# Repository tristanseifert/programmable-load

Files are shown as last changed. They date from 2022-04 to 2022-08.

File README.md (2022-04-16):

# Programmable Load
A DC programmable load with lots of fun and exciting features, featuring firmware that doesn't suck.

Additional documentation [is available here.](https://wiki.trist.network/books/programmable-load) You can also read about some of the progress on my blog, [starting here.](https://blraaz.me/hardware/2022/04/13/programmable-load-intro.html)

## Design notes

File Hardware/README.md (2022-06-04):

Here is where the hardware part of the project lives. This consists of a few different boards:

- analog: A 300W load board, based around up to four individual channels, each with their own MOSFET and current sense resistor. Each channel may be individually controlled, and its current individually sensed via a 24-bit ADC. Both the ADC and current drive DAC are connected via a high-speed SPI bus. The board also features a precision 2.5V voltage reference shared by all analog components, as well as a programmable clock generator for the ADC sampling clock.
- controller: Main board, in charge of communicating with external devices (via USB or Ethernet,) driving the user interface, and running the actual control loop for whatever algorithm is desired. It also contains the analog circuitry for sensing input voltage from one of several sources.
- driver: Old I2C-based analog load board. No longer supported, should be removed soon.
- front: Front panel board; features some indicator lights, buttons, and breakout for the display. Mounted vertically to front panel of the system.
- front-bonus-display: An additional secondary (optional) character display, adjacent to the input jacks. It's used to display some information about the current set point, drawn current/voltage, and so forth in addition to the main display.
- rear: Various connectors exposed on the rear of the device, such as USB and Ethernet. It also has a pulse shaper for the external trigger. It's mounted parallel to the rear panel of the system.

All of these boards connect to the controller in some way, shape or form. Each board in turn has an EEPROM, which identifies its type, and provides a unique serial number. This is used by the software to figure out what's connected, and what features to offer.

## Front Panels
The `panels` directory contains front and rear panels, designed with [Front Panel Designer](https://www.frontpanelexpress.com/front-panel-designer) and to be manufactured by Front Panel Express. These panels are meant to replace the existing bare aluminum panels that come standard with a [Hammond 1598JBK](https://www.hammfg.com/part/1598JBK) enclosure, for which the boards are designed.

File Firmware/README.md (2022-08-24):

# Programmable Load Firmware
This directory contains the real-time firmware for the programmable load, to be built using the llvm (version 13) `arm-none-unknown-eabi` toolchain. It runs on the M4 core of the [STM32MP151 SoC](https://www.st.com/en/microcontrollers-microprocessors/stm32mp151.html) the programmable load is built around, running its own RTOS. It communicates with the host software (there, its counterpart is `loadd`) for remote control using the OpenAMP framework's rpmsg facilities.

Notable features include:
- Based around FreeRTOS
- Versatile set of control modes
- Clean, easily hackable code

## Building
To get started with the code, ensure you have a CMake toolchain file for your ARM toolchain. Inside a build directory (in this case, `build`) issue the following commands:

```
mkdir build
cmake -G Ninja -B build -DCMAKE_TOOLCHAIN_FILE=path/to/toolchain.cmake -DCMAKE_BUILD_TYPE=RelWithDebInfo
cmake --build build
```

## Hardware Support
Currently, only the rev 3 programmable load controller board is supported, though adding support for later reivsions is simple: this firmware has a very limited set of peripherals under its purview.

### Analog Board Support
Various types of analog boards can be supported, connected via the dedicated SPI + I²C busses. Boards are identified by means of an AT24CS32-style EEPROM on the I²C bus, which is then used to instantiate the appropriate driver in the firmware. This EEPROM also provides the board's unique serial number, as well as some additional manufacturing information, and any auxiliary board-specific data the driver needs to store (such as calibration or limits) and access at runtime.

Supported analog boards (and their drivers) are:

** None yet! Check back later :) **

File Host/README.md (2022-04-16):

# Programmable Load Host Tools
This directory contains a variety of tools that run on a computer connected to the load via USB or Ethernet.

## libload
This library implements USB communication with the load. Internally, it's a thin wrapper around libusb that provides a nicer C++ interface to the device.

When/if the load is updated to support TCP/IP communication, this library will be updated to handle that as well.

## loadutil
A command line utility, which embeds libload, used to communicate with the programmable load. This allows basic tasks like retrieving device information, controlling the device, and accessing some additional internal functions.

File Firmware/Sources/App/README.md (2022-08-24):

# Application Tasks
In this directory you'll find the application specific tasks:

- Control: Interfaces to the physical load driver hardware, collects sensor measurements and updates drive DACs.
- Rpmsg: Processes messages received from remote endpoint; handle periodic data/measurement updates

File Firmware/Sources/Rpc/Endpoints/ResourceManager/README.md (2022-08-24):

# Resource Manager RPC
This provides a driver for the remoteproc resource manager (`rproc_srm_*` kernel modules in the [ST Linux fork](https://github.com/STMicroelectronics/linux/tree/v5.15-stm32mp/drivers/remoteproc)) RPC interface. It's used to inform the Linux side of required clock and voltage regulator resources, as well as deal with peripheral assignments/reservations.

## License
Some of this code is based on ST's [STM32CubeMP1 res_mgr.c](https://github.com/STMicroelectronics/STM32CubeMP1/tree/8206e534360c77f22f616243c3ccf9311af83f33/Utilities/ResourcesManager) code, licensed under the BSD 3-clause license:

> Redistribution and use in source and binary forms, with or without modification, are permitted provided that the following conditions are met:
>
> 1. Redistributions of source code must retain the above copyright notice, this list of conditions and the following disclaimer.
> 2. Redistributions in binary form must reproduce the above copyright notice, this list of conditions and the following disclaimer in the documentation and/or other materials provided with the distribution.
> 3. Neither the name of STMicroelectronics nor the names of its contributors may be used to endorse or promote products derived from this software without specific prior written permission.
>
> THIS SOFTWARE IS PROVIDED BY THE COPYRIGHT HOLDERS AND CONTRIBUTORS "AS IS" AND ANY EXPRESS OR IMPLIED WARRANTIES, INCLUDING, BUT NOT LIMITED TO, THE IMPLIED WARRANTIES OF MERCHANTABILITY AND FITNESS FOR A PARTICULAR PURPOSE ARE DISCLAIMED. IN NO EVENT SHALL THE COPYRIGHT HOLDER OR CONTRIBUTORS BE LIABLE FOR ANY DIRECT, INDIRECT, INCIDENTAL, SPECIAL, EXEMPLARY, OR CONSEQUENTIAL DAMAGES (INCLUDING, BUT NOT LIMITED TO, PROCUREMENT OF SUBSTITUTE GOODS OR SERVICES; LOSS OF USE, DATA, OR PROFITS; OR BUSINESS INTERRUPTION) HOWEVER CAUSED AND ON ANY THEORY OF LIABILITY, WHETHER IN CONTRACT, STRICT LIABILITY, OR TORT (INCLUDING NEGLIGENCE OR OTHERWISE) ARISING IN ANY WAY OUT OF THE USE OF THIS SOFTWARE, EVEN IF ADVISED OF THE POSSIBILITY OF SUCH DAMAGE.

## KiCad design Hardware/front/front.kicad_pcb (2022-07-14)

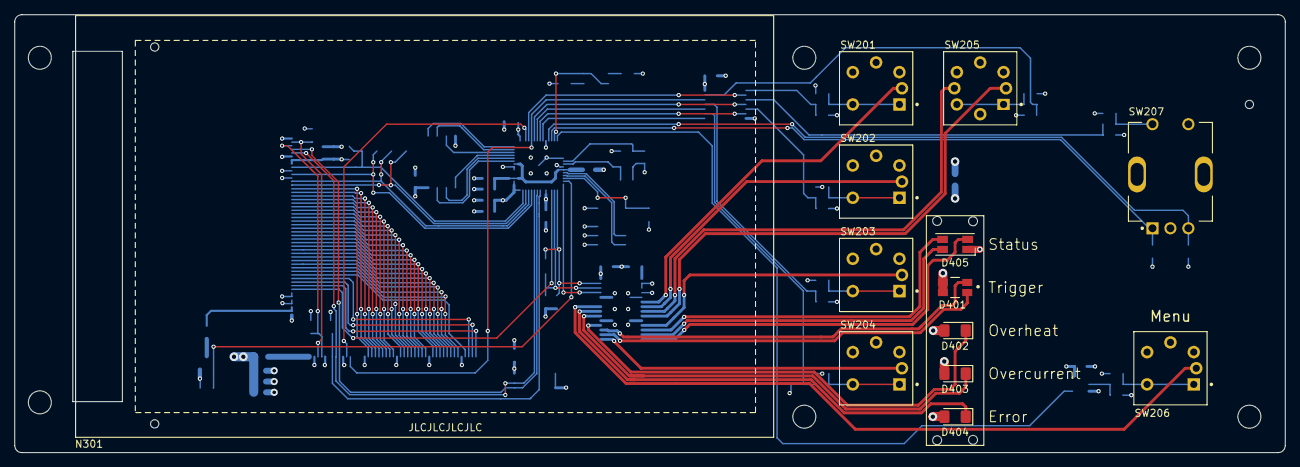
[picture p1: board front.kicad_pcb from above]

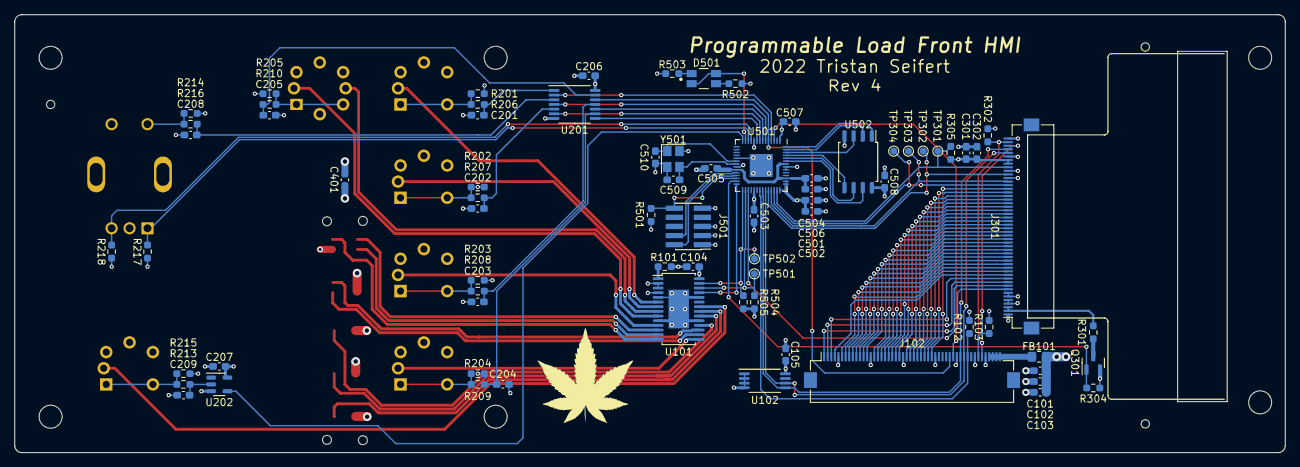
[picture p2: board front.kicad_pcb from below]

Board: 4 copper layers, 177.0 x 61.0 mm, 96 parts (74 on the bottom side), 102 nets.

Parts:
C101, C104, C105, C206, C207, C302, C501, C503, C504, C505, C507, C508: 100nF; C_0603_1608Metric_Pad1.08x0.95mm_HandSolder
C102, C103: 22µF; C_0603_1608Metric_Pad1.08x0.95mm_HandSolder
C201, C202, C203, C204, C205, C208, C209, C301, C401, C502, C506: 4.7µF; C_0603_1608Metric_Pad1.08x0.95mm_HandSolder
C509, C510: 18pF; C_0603_1608Metric_Pad1.08x0.95mm_HandSolder
D401, D501: LED_Dual_AAKK; LED-3227
D402, D403: Yellow; LED_1206_3216Metric_Pad1.42x1.75mm_HandSolder
D404: Red; LED_1206_3216Metric_Pad1.42x1.75mm_HandSolder
D405: LED_RGBA; LED_RGB_1210
FB101: FerriteBead_Small; R_0805_2012Metric_Pad1.20x1.40mm_HandSolder
H101, H102, H103, H104, H105, H106: MountingHole; MountingHole_3.2mm_M3
H107, H108, H109: MountingHole; JLCPCB-SmdAssembly-ToolingHole
J102, J301: Conn_02x25_Counter_Clockwise; Hirose_FH12-50S-0.5SH_1x50-1MP_P0.50mm_Horizontal
J501: Conn_ARM_JTAG_SWD_10; PinHeader_2x05_P1.27mm_Vertical_SMD
N301: ER-TFT040-1
Q301: AO3400A; SOT-23
R101: 2k; R_0603_1608Metric_Pad0.98x0.95mm_HandSolder
R102, R103, R201, R202, R203, R204, R205, R214, R215, R217, R218, R302, R304, R305, R501: 10k; R_0603_1608Metric_Pad0.98x0.95mm_HandSolder
R206, R207, R208, R209, R210, R213, R216, R502, R503: 1k; R_0603_1608Metric_Pad0.98x0.95mm_HandSolder
R301: 2R2; R_0603_1608Metric_Pad0.98x0.95mm_HandSolder
R504, R505: 2k2; R_0603_1608Metric_Pad0.98x0.95mm_HandSolder
SW201, SW202, SW203, SW204: B3W-9002-Y1C; Omron-B3W-90XX-X1X
SW205: B3W-9000-RHG2C; Omron-B3W-90XX-X2X
SW206: B3W-9002-G1G; Omron-B3W-90XX-X1X
SW207: TT EN11; TT_Electronics-EN11-HSM1AF15-0
TP301: /SPI_CS; TestPoint_Pad_D1.0mm
TP302: SPI_SCK; TestPoint_Pad_D1.0mm
TP303: SPI_MOSI; TestPoint_Pad_D1.0mm
TP304: SPI_MISO; TestPoint_Pad_D1.0mm
TP501: I²C_SCL; TestPoint_Pad_D1.0mm
TP502: I²C_SDA; TestPoint_Pad_D1.0mm
U101: PCA9955B; HTSSOP-28-1EP_4.4x9.7mm_P0.65mm_EP2.85x5.4mm
U102: AT24CS32-XHM; TSSOP-8_4.4x3mm_P0.65mm
U201: 74LV14; TSSOP-14_4.4x5mm_P0.65mm
U202: 74LVC1G14GV; SOT-23-5
U501: RP2040; QFN-56-1EP_7x7mm_P0.4mm_EP3.2x3.2mm
U502: W25Q128JVS; SOIC-8_5.23x5.23mm_P1.27mm
Y501: 12MHz; Crystal_SMD_3225-4Pin_3.2x2.5mm

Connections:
+1V1: C504.1, C505.1, C506.1, U501.23 (DVDD), U501.45 (VREG_VOUT), U501.50 (DVDD)
+3V3: C101.1, C102.1, C103.1, C104.1, C105.1, C206.1, C207.1, C301.1, C302.1, C401.1, C501.1, C502.1, C503.1, C507.1, C508.1, D401.1 (A1), D401.2 (A2), D402.2 (A), D403.2 (A), D404.2 (A), D405.1 (A), FB101.2, J301.1, J301.4, J301.5, J301.39, J301.41, J301.43, J301.44, J501.1 (VTref), R102.2, R103.2, R201.2, R202.2, R203.2, R204.2, R205.2, R214.2, R215.2, R217.1, R218.1, R302.2, R305.2, R501.2, R502.1, R504.2, R505.2, SW201.A, SW202.A, SW203.A, SW204.A, SW205.A1, SW205.A2, SW206.A, U101.4 (AD2), U101.28 (VCC), U102.8 (VCC), U201.14 (3.3V), U202.5 (VCC), U501.1 (IOVDD), U501.10 (IOVDD), U501.22 (IOVDD), U501.33 (IOVDD), U501.42 (IOVDD), U501.43 (ADC_AVDD), U501.44 (VREG_IN), U501.48 (USB_VDD), U501.49 (IOVDD), U502.8 (VCC)
/B0: J102.31, J301.36
/B1: J102.30, J301.35
/B2: J102.29, J301.34
/B3: J102.28, J301.33
/B4: J102.27, J301.32
/B5: J102.26, J301.31
/B6: J102.25, J301.30
/B7: J102.24, J301.29
/DISP_DE: J102.4, J301.12
/DISP_HSYNC: J102.2, J301.10
/DISP_PCLK: J102.3, J301.11
/DISP_PWM: Q301.1 (G), R304.1, U501.27 (GPIO16)
/DISP_SCL: R504.1, TP501.1, U101.26 (SCL), U501.30 (GPIO19)
/DISP_SDA: R505.1, TP502.1, U101.27 (SDA), U501.29 (GPIO18)
/DISP_VSYNC: J102.1, J301.9
/ENCODER_A: R217.2, SW207.A, U501.12 (GPIO9)
/ENCODER_B: R218.2, SW207.B, U501.11 (GPIO8)
/Embedded Controller/FLASH_IO0: U501.53 (QSPI_SD0), U502.5 (DI(IO0))
/Embedded Controller/FLASH_IO1: U501.55 (QSPI_SD1), U502.2 (DO(IO1))
/Embedded Controller/FLASH_IO2: U501.54 (QSPI_SD2), U502.3 (IO2)
/Embedded Controller/FLASH_IO3: U501.51 (QSPI_SD3), U502.7 (IO3)
/Embedded Controller/FLASH_SCK: U501.52 (QSPI_SCLK), U502.6 (CLK)
/Embedded Controller/STATUSLED: D501.2 (A2), D501.3 (K1), U501.13 (GPIO10)
/Embedded Controller/SWCLK: J501.4 (SWDCLK/TCK), U501.24 (SWCLK)
/Embedded Controller/SWD: J501.2 (SWDIO/TMS), U501.25 (SWD)
/Embedded Controller/XIN: C510.1, U501.20 (XIN), Y501.1
/Embedded Controller/XOUT: C509.1, U501.21 (XOUT), Y501.3
/Embedded Controller/~FLASH_CS: U501.56 (QSPI_SS), U502.1 (~CS)
/Embedded Controller/~RESET: J501.10 (~RESET), R501.1, U501.26 (RUN)
/G0: J102.22, J301.28
/G1: J102.21, J301.27
/G2: J102.20, J301.26
/G3: J102.19, J301.25
/G4: J102.18, J301.24
/G5: J102.17, J301.23
/G6: J102.16, J301.22
/G7: J102.15, J301.21
/LCD, Backlight driver/LEDK: J301.2, J301.3, R301.1
/LED_EN_G: SW205.K2 (K), U101.8 (LED2)
/LED_EN_R: SW205.K1 (K), U101.9 (LED3)
/LED_ERROR: D404.1 (K), U101.21 (LED13)
/LED_MENU: SW206.K, U101.22 (LED14)
/LED_MODE_CC: SW201.K, U101.6 (LED0)
/LED_MODE_CV: SW202.K, U101.7 (LED1)
/LED_MODE_CW: SW203.K, U101.11 (LED4)
/LED_MODE_EXT: SW204.K, U101.15 (LED8)
/LED_OVRCURR: D403.1 (K), U101.20 (LED12)
/LED_OVRHEAT: D402.1 (K), U101.18 (LED11)
/LED_STATUS_B: D405.4 (BK), U101.13 (LED6)
/LED_STATUS_G: D405.3 (GK), U101.12 (LED5)
/LED_STATUS_R: D405.2 (RK), U101.14 (LED7)
/LED_TRIGGER1: D401.3 (K1), U101.17 (LED10)
/LED_TRIGGER2: D401.4 (K2), U101.16 (LED9)
/R0: J102.13, J301.20
/R1: J102.12, J301.19
/R2: J102.11, J301.18
/R3: J102.10, J301.17
/R4: J102.9, J301.16
/R5: J102.8, J301.15
/R6: J102.7, J301.14
/R7: J102.6, J301.13
/SCL: J102.40, J301.46, U102.6 (SCL), U501.37 (GPIO25)
/SDA: J102.39, J301.47, U102.5 (SDA), U501.36 (GPIO24)
/SPI_MISO: J301.37, TP304.1, U501.40 (GPIO28_ADC2)
/SPI_MOSI: J301.38, TP303.1, U501.39 (GPIO27_ADC1)
/SPI_SCK: J301.40, TP302.1, U501.38 (GPIO26_ADC0)
/SW_ENABLE: J102.36, U201.12, U501.5 (GPIO3)
/SW_ENCODER: U201.4, U501.6 (GPIO4)
/SW_MENU: U202.4, U501.14 (GPIO11)
/SW_MODE_CC: U201.2, U501.4 (GPIO2)
/SW_MODE_CV: U201.6, U501.8 (GPIO6)
/SW_MODE_CW: U201.10, U501.7 (GPIO5)
/SW_MODE_EXT: U201.8, U501.9 (GPIO7)
/~DISP_RESET: J301.8, U501.31 (GPIO20)
/~HOST_IRQ: J102.41, R102.1, U501.35 (GPIO23)
/~LED_RESET: U101.25 (~RESET), U501.28 (GPIO17)
/~SPI_CS: J301.42, R305.1, TP301.1, U501.41 (GPIO29_ADC3)
/~SYS_RESET: J102.37, U501.3 (GPIO1)
/~TOUCH_IRQ: J102.44, J301.48, R103.1
/~TOUCH_RESET: J102.45, J301.49, R302.1
GND: C101.2, C102.2, C103.2, C104.2, C105.2, C201.2, C202.2, C203.2, C204.2, C205.2, C206.2, C207.2, C208.2, C209.2, C301.2, C302.2, C401.2, C501.2, C502.2, C503.2, C504.2, C505.2, C506.2, C507.2, C508.2, C509.2, C510.2, J102.5, J102.14, J102.23, J102.32, J102.38, J102.43, J102.46, J301.6, J301.7, J301.45, J301.50, J501.3 (GND), J501.5 (GND), J501.9 (GNDDetect), Q301.2 (S), R101.1, R304.2, R503.1, SW201.3, SW201.4, SW202.3, SW202.4, SW203.3, SW203.4, SW204.3, SW204.4, SW205.3, SW205.4, SW206.3, SW206.4, SW207.C, SW207.S2, U101.2 (AD0), U101.3 (AD1), U101.5 (~OE), U101.10 (GND), U101.19 (GND), U101.24 (GND), U101.29 (GND), U102.1 (A0), U102.2 (A1), U102.3 (A2), U102.4 (GND), U201.7 (GND), U202.3 (GND), U501.19 (TESTEN), U501.57 (GND), U502.4 (GND), Y501.2, Y501.4
unnamed: C201.1, R206.2, U201.1
unnamed: C202.1, R207.2, U201.5
unnamed: C203.1, R208.2, U201.11
unnamed: C204.1, R209.2, U201.9
unnamed: C205.1, R210.2, U201.13
unnamed: C208.1, R216.2, U201.3
unnamed: C209.1, R213.1, U202.2
unnamed: D501.1 (A1), R502.2
unnamed: D501.4 (K2), R503.2
unnamed: FB101.1, J102.47, J102.48, J102.49, J102.50
unnamed: Q301.3 (D), R301.2
unnamed: R201.1, R206.1, SW201.1, SW201.2
unnamed: R202.1, R207.1, SW202.1, SW202.2
unnamed: R203.1, R208.1, SW203.1, SW203.2
unnamed: R204.1, R209.1, SW204.1, SW204.2
unnamed: R205.1, R210.1, SW205.1, SW205.2
unnamed: R213.2, R215.1, SW206.1, SW206.2
unnamed: R214.1, R216.1, SW207.S1
unnamed: R101.2, U101.1 (REXT)

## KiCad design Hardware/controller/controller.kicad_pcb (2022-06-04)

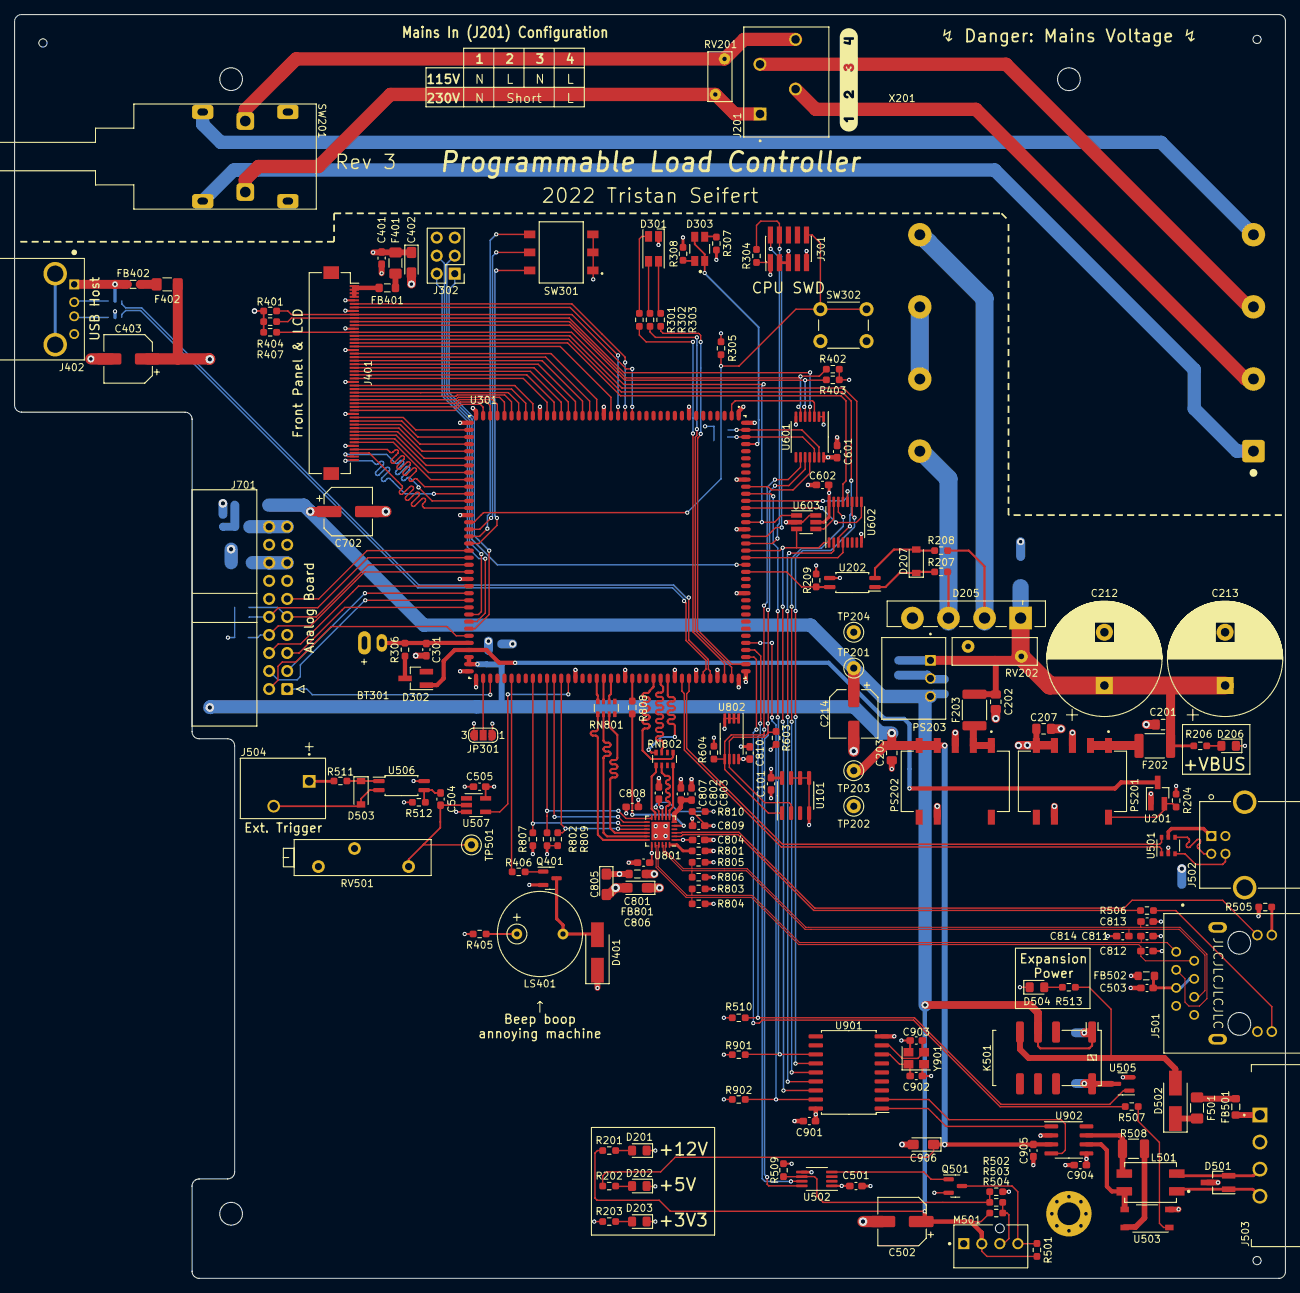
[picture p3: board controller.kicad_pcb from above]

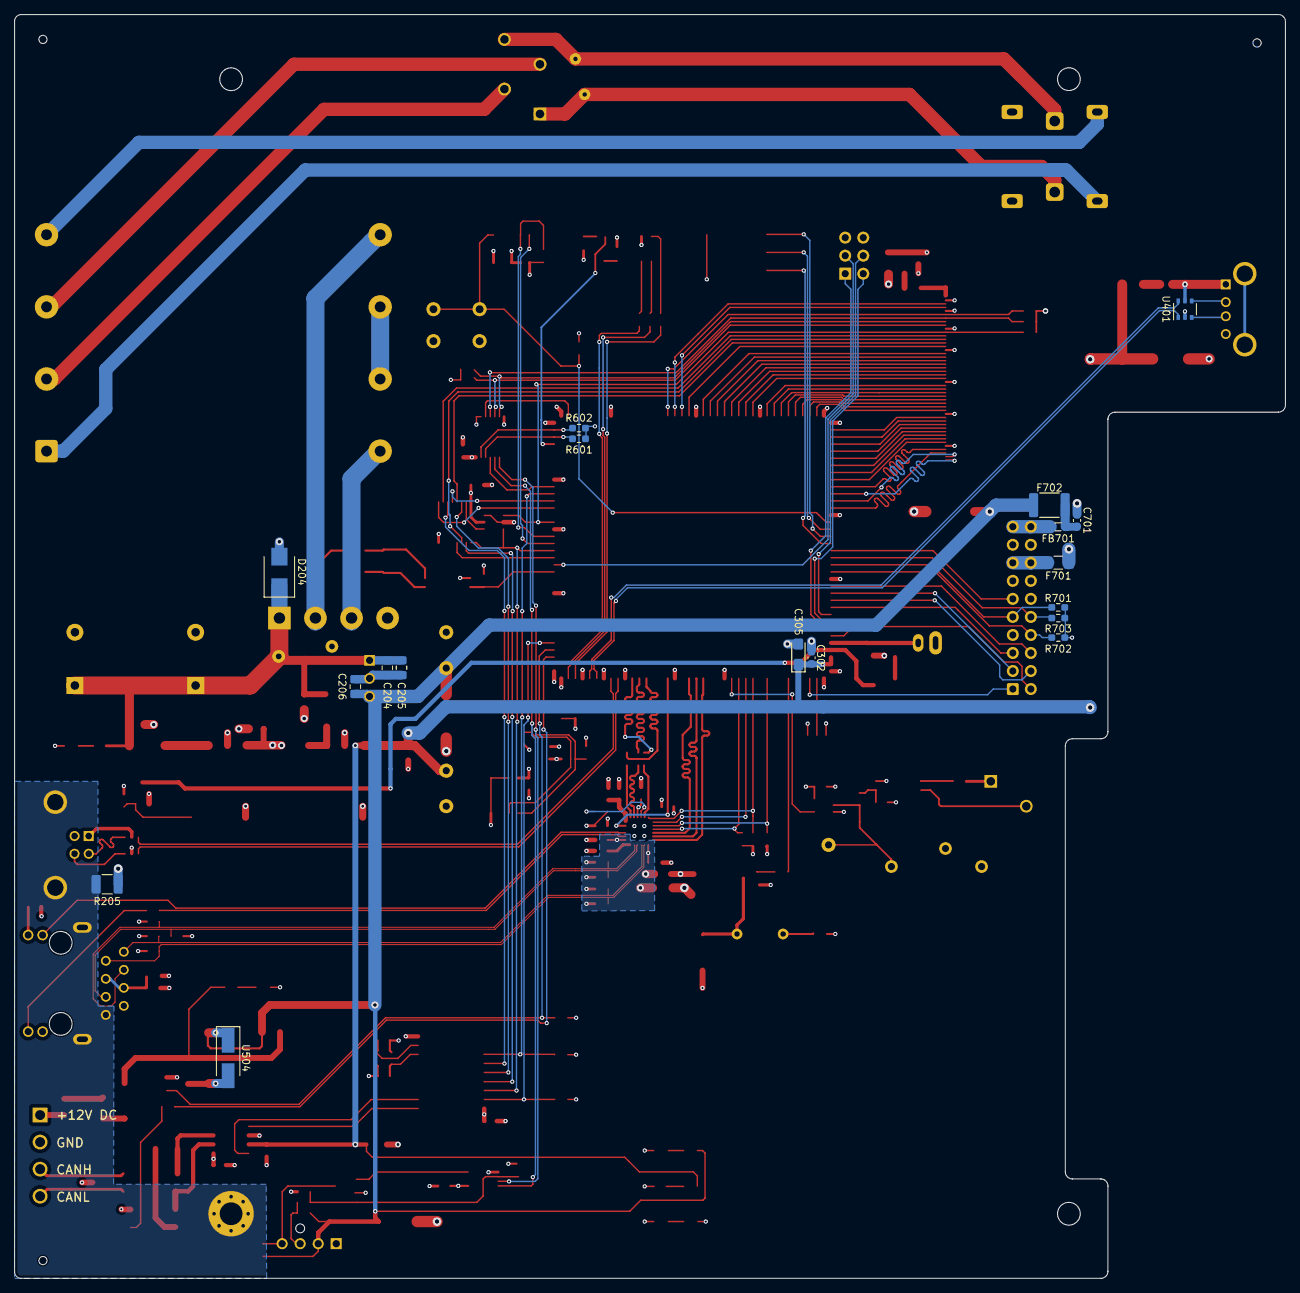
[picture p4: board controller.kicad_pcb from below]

Board: 4 copper layers, 179.0 x 178.0 mm, 193 parts (18 on the bottom side), 192 nets.

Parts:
BT301: ML-1220; Panasonic-ML-1220_V1AN-0-0
C101, C301, C302, C401, C501, C505, C601, C602, C701, C810, C901, C904, C905: 100nF; C_0603_1608Metric_Pad1.08x0.95mm_HandSolder
C201, C202, C204, C205, C206: 10µF; C_0805_2012Metric_Pad1.18x1.45mm_HandSolder
C203, C207: 22µF; C_0805_2012Metric_Pad1.18x1.45mm_HandSolder
C212, C213: 3300µF; CP_Radial_D16.0mm_P7.50mm
C214, C403, C502, C702: 33µF; CP_Elec_6.3x5.7
C305, C402, C805, C806, C906: 10µF; CP_EIA-3216-18_Kemet-A_Pad1.58x1.35mm_HandSolder
C503: 22nF; C_0603_1608Metric_Pad1.08x0.95mm_HandSolder
C504, C803: 1µF; C_0603_1608Metric_Pad1.08x0.95mm_HandSolder
C801, C804, C807, C808, C809: 10nF; C_0603_1608Metric_Pad1.08x0.95mm_HandSolder
C802: 470pF; C_0603_1608Metric_Pad1.08x0.95mm_HandSolder
C811, C812, C813, C814: 22pF; C_0603_1608Metric_Pad1.08x0.95mm_HandSolder
C902, C903: 15pF; C_0603_1608Metric_Pad1.08x0.95mm_HandSolder
D201, D202, D203, D206, D504: Green; LED_0805_2012Metric_Pad1.15x1.40mm_HandSolder
D204: 824521241; D_SMB
D205: GBU4M; Diode_Bridge_Vishay_GBU
D207, D503: 1N4148W; D_SOD-123
D301: LED_RGBA; LED_RGB_1210
D302: BAS40HE3; SOT-23_Handsoldering
D303: LED_Dual_AAKK; LED-3227
D401: SM4007; D_SMA_Handsoldering
D501: ESDONCAN1; SOT-23_Handsoldering
D502: Panjit SS14; D_SMA_Handsoldering
F202, F203: .3A; Fuse_1812_4532Metric_Pad1.30x3.40mm_HandSolder
F401, F402, F501, F701: 500mA; Fuse_1206_3216Metric_Pad1.42x1.75mm_HandSolder
F702: 1.6A; Fuse_1812_4532Metric_Pad1.30x3.40mm_HandSolder
FB401, FB402, FB501, FB502, FB701, FB801: FerriteBead_Small; L_0805_2012Metric_Pad1.05x1.20mm_HandSolder
H101, H102, H104: MountingHole; MountingHole_3.2mm_M3
H103: MountingHole; MountingHole_3.2mm_M3_Pad_Via
H105, H106, H107: MountingHole; JLCPCB-SmdAssembly-ToolingHole
J201: Conn_01x04; CUI_TBL002A-350-04GR-2OR
J301: Conn_ARM_JTAG_SWD_10; PinHeader_2x05_P1.27mm_Vertical_SMD
J302: Conn_02x03_Odd_Even; PinHeader_2x03_P2.54mm_Vertical
J401: Conn_02x25_Counter_Clockwise; Hirose_FH12-50S-0.5SH_1x50-1MP_P0.50mm_Horizontal
J402: USB_A; CUI_UJ2-AH-4-TH
J501: ARJM11C7-009-AB; Abracon-ARJM11C7
J502: USB_B; CUI_UJ2-BH-2-TH
J503: TBP02R1W-381-04BE; CUI_TBP02R1W-381-04BE
J504: Screw_Terminal_01x02; CUI_TBL002A-350-02GR-2OR
J701: Conn_02x10_Odd_Even; IDC-Header_2x10_P2.54mm_Horizontal
JP301: SolderJumper_3_Open; SolderJumper-3_P1.3mm_Open_RoundedPad1.0x1.5mm_NumberLabels
K501: EE2-12NU; Relay_DPDT_Kemet_EE2_NU
L501: DR331-513BE; Bourns-DR331-0-0-MFG
LS401: Speaker; PUI-AT-1224-TWT
M501: Fan_4pin; Molex-47053-1000-MFG
PS201: V78E03-1000-SMT-TR; CONV_V78E03-1000-SMT-TR
PS202: V78E05-1000-SMT-TR; CONV_V78E03-1000-SMT-TR
PS203: P7812-2000-S; CONV_P7812-2000-S
Q401, Q501: MMBT3904; SOT-23
R201, R209, R501, R504, R510, R513: 4k7; R_0603_1608Metric_Pad0.98x0.95mm_HandSolder
R202, R402, R403, R601, R602, R603, R604, R701, R702, R802, R807: 2k2; R_0603_1608Metric_Pad0.98x0.95mm_HandSolder
R203, R301, R302, R303, R304, R307, R308, R507: 1k; R_0603_1608Metric_Pad0.98x0.95mm_HandSolder
R204, R305, R401, R404, R407, R502, R509, R703, R809, R810, R901, R902: 10k; R_0603_1608Metric_Pad0.98x0.95mm_HandSolder
R205: 0R; R_1210_3225Metric_Pad1.30x2.65mm_HandSolder
R206, R207, R208: 7k5; R_0603_1608Metric_Pad0.98x0.95mm_HandSolder
R306: 100R; R_0603_1608Metric_Pad0.98x0.95mm_HandSolder
R405, R406, R505, R506: 330R; R_0603_1608Metric_Pad0.98x0.95mm_HandSolder
R503: 27k4; R_0603_1608Metric_Pad0.98x0.95mm_HandSolder
R508: 100R; R_1210_3225Metric_Pad1.30x2.65mm_HandSolder
R511: 200R; R_0603_1608Metric_Pad0.98x0.95mm_HandSolder
R512: 47k; R_0603_1608Metric_Pad0.98x0.95mm_HandSolder
R801: 12k1 1%; R_0603_1608Metric_Pad0.98x0.95mm_HandSolder
R803, R804, R805, R806: 49R9; R_0603_1608Metric_Pad0.98x0.95mm_HandSolder
R808: 33R; R_0603_1608Metric_Pad0.98x0.95mm_HandSolder
RN801, RN802: 33R; R_Array_Convex_4x0603
RV201: Varistor; RV_Disc_D7mm_W3.4mm_P5mm
RV202: 470KD10; RV_Disc_D12mm_W3.9mm_P7.5mm
RV501: 500k; Potentiometer_Bourns_3006P_Horizontal
SW201: NE1838EE
SW301: SW_DIP_x03; CUI-DS04-254-2-03BK-SMT
SW302: SW_MEC_5E; SW_PUSH_6mm
TP201: +12V; TestPoint_Keystone_5000-5004_Miniature
TP202: +3V3; TestPoint_Keystone_5000-5004_Miniature
TP203: +5V; TestPoint_Keystone_5000-5004_Miniature
TP204: GND; TestPoint_Keystone_5000-5004_Miniature
TP501: Trigger; TestPoint_Keystone_5000-5004_Miniature
U101: LM75B; SOIC-8_3.9x4.9mm_P1.27mm
U201: TCM809TVNB713; SOT-23_Handsoldering
U202, U506: FODM217B; SOP-4_4.4x2.6mm_P1.27mm
U301: MYC-YA151C-4E512D-65-C-T; MYCYA151C4E512D65CT
U401, U501: IP4234CZ6-ALT; TSOP-6_1.65x3.05mm_P0.95mm
U502: EMC2101-R; MSOP-8_3x3mm_P0.65mm
U503: TLP170A; MFSOP6-4_4.4x3.6mm_P1.27mm
U504: SM4007; D_SMA_Handsoldering
U505: MMBT3904; SOT-23
U507: 74LVC1G17; SOT-23-5_HandSoldering
U601: PCA9543A; TSSOP-14_4.4x5mm_P0.65mm
U602: SN74CBTLV3257; TSSOP-16_4.4x5mm_P0.65mm
U603: 74LVC1G0832; SOT-23-6_Handsoldering
U801: LAN8720A; QFN-24-1EP_4x4mm_P0.5mm_EP2.6x2.6mm
U802: AT24MAC402; TSSOP-8_4.4x3mm_P0.65mm
U901: MCP2515-xSO; SOIC-18W_7.5x11.6mm_P1.27mm
U902: MCP2542WFD; SOIC-8_3.9x4.9mm_P1.27mm
X201: FS20-1800-C2; Triad-FS16-2250-C2
Y901: 16MHz; Crystal_SMD_3225-4Pin_3.2x2.5mm
kibuzzard-62915F53: G***; kibuzzard-62915F53

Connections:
+3V3: C101.2, C207.1, C401.2, C402.1, C501.2, C505.2, C601.1, C602.1, C805.1, C807.1, C808.1, C809.1, C810.2, C901.1, C904.1, D301.1 (A), D401.1 (K), F401.1, F701.1, FB502.1, FB801.1, J301.1 (VTref), J302.6, J501.9 (RLED+), JP301.3 (B), PS201.4 (+VOUT), PS201.5 (+VOUT), R203.1, R209.1, R304.2, R305.2, R307.1, R401.2, R402.2, R403.2, R404.2, R405.2, R407.2, R509.1, R601.2, R602.2, R603.2, R604.2, R701.2, R702.2, R703.2, R802.1, R807.1, R809.2, R810.1, R901.2, R902.2, SW301.1, SW301.2, SW301.3, TP202.1, U101.8 (+Vs), U502.1 (VCC), U506.4, U507.5 (VCC), U601.14 (VCC), U602.16 (VCC), U603.5 (VCC), U801.9 (VDDIO), U802.8 (VCC), U901.18 (VDD), U902.5 (VIO)
+3V3A: C801.1, C804.1, C806.1, FB801.2, R803.1, R804.1, R805.1, R806.1, U801.1 (VDD2A), U801.19 (VDD1A)
+5V: C203.1, C302.1, C305.1, C403.1, C905.1, C906.1, F402.2, PS202.4 (+VOUT), PS202.5 (+VOUT), R202.1, TP203.1, U301.72 (VDD_{5V}), U301.73 (VDD_{5V}), U902.3 (VCC)
+12V: C206.2, C214.1, C502.1, C702.1, F702.2, K501.1, K501.4, M501.2 (+), PS203.3 (+VO), R201.1, R501.2, R504.2, TP201.1, U504.1 (K)
+BATT: BT301.1 (+), C301.1, R306.2, U301.70 (V_{BAT})
/ANA_MISO: J701.3, U301.63 (PH7)
/ANA_MOSI: J701.6, U301.62 (PF11)
/ANA_SCK: J701.5, U301.65 (PH6)
/ANA_SCL: J701.9, R701.1, U301.59 (PF14)
/ANA_SDA: J701.8, R702.1, U301.60 (PF15)
/ANA_SEL0: J701.4, U301.64 (PH5)
/ANA_SEL1: J701.2, U301.69 (PA12)
/ANA_SEL2: J701.1, U301.77 (PE11)
/BEEPER: R406.1, U301.80 (PA3)
/CANH: L501.3, R508.2, U902.7 (CANH)
/CANL: L501.4, U503.4, U902.6 (CANL)
/CAN_TERM_EN: R507.2, U301.115 (PF7)
/CPU/BOOT0: SW301.4, U301.55 (BOOT0)
/CPU/BOOT1: SW301.5, U301.54 (BOOT1)
/CPU/BOOT2: SW301.6, U301.56 (BOOT2)
/CPU/Bus Multiplexers/~SPI_MUX_OE: U602.15 (~OE), U603.4
/CPU/CAN_SPI_MISO: U602.14 (4B1), U901.14 (SI)
/CPU/CAN_SPI_MOSI: U602.2 (1B1), U901.15 (SO)
/CPU/CAN_SPI_SCK: U602.11 (3B1), U901.13 (SCK)
/CPU/ETH_CLK: R808.1, U301.97 (PA1/ETH_RCLK)
/CPU/ETH_CRS_DV: RN802.8 (R1.2), U301.102 (PA7/ETH_RCTL)
/CPU/ETH_MDC: U301.86 (PC1/ETH_MDC), U801.13 (MDC)
/CPU/ETH_MDIO: R802.2, U301.85 (PA2/ETH_MDIO), U801.12 (MDIO)
/CPU/ETH_RXD0: RN802.7 (R2.2), U301.101 (PC4/ETH_RD0)
/CPU/ETH_RXD1: RN802.5 (R4.2), U301.100 (PC5/ETH_RD1)
/CPU/ETH_TXD0: RN801.7 (R2.2), U301.93 (PG13/ETH_TD0)
/CPU/ETH_TXD1: RN801.8 (R1.2), U301.92 (PG14/ETH_TD1)
/CPU/ETH_TX_EN: RN801.6 (R3.2), U301.94 (PB11/ETH_TCTL)
/CPU/Ethernet PHY/RXER: R810.2, U801.10 (RXER/PHYAD0)
/CPU/Expansion CAN Controller/CAN_RX: U901.2 (RXCAN), U902.4 (RXD)
/CPU/Expansion CAN Controller/CAN_TX: U901.1 (TXCAN), U902.1 (TXD)
/CPU/Expansion CAN Controller/OSC1: C903.1, U901.8 (OSC1), Y901.3
/CPU/Expansion CAN Controller/OSC2: C902.1, U901.7 (OSC2), Y901.1
/CPU/I2C2_SCL: R601.1, U301.146 (PH4), U601.12 (SCL)
/CPU/I2C2_SDA: R602.1, U301.147 (PZ7), U601.13 (SDA)
/CPU/SOM_PWRON: JP301.2 (C), U301.76 (KEY_WP)
/CPU/SPI3_MISO: U301.137 (PC11/MMC1_D3), U602.12 (4A)
/CPU/SPI3_MOSI: U301.129 (PB2), U602.4 (1A)
/CPU/SPI3_SCK: U301.136 (PC10/MMC1_D2), U602.9 (3A)
/CPU/STATUS_A7: D303.2 (A2), D303.3 (K1), U301.145 (PZ6)
/CPU/STATUS_B: R303.1, U301.114 (PF8)
/CPU/STATUS_G: R302.1, U301.111 (PD13)
/CPU/STATUS_R: R301.1, U301.110 (PG5)
/CPU/SWDCLK: J301.4 (SWDCLK/TCK), R304.1, U301.132 (SWCLK)
/CPU/SWDIO: J301.2 (SWDIO/TMS), U301.131 (SWDIO)
/CPU/TTY1_RX: J302.1, U301.68 (PA11)
/CPU/TTY1_TX: J302.3, U301.128 (PG11)
/CPU/TTY2_RX: J302.2, U301.67 (PB5)
/CPU/TTY2_TX: J302.4, U301.66 (PB13)
/CPU/~CAN_RESET: R902.1, U301.117 (PF9), U901.17 (~RESET)
/CPU/~CAN_SPI_CS: U301.130 (PA15), U602.1 (S), U603.3, U901.16 (~CS)
/CPU/~ETH_PHY_IRQ: R807.2, U301.83 (PA5), U801.14 (INT/REFCLKO)
/CPU/~ETH_PHY_RESET: R809.1, U301.87 (PC0), U801.15 (RST)
/CPU/~I2CMUX_IRQ: U301.139 (PD2/MMC1_CMD), U601.11 (~INT)
/CPU/~I2CMUX_RESET: U301.2 (PF0/MMC3_D0), U601.3 (~RESET)
/CPU/~RESET: J301.10 (~RESET), R305.1, SW302.1, U301.53 (~RESET)
/CPU/~SPI3_IRQ: R901.1, U301.138 (PC12/MMC1_CK), U901.12 (~INT)
/CPU_3V3: D302.1, U201.3 (VCC), U301.71 (3V3_{OUT})
/DISP_MISO: J401.17, U602.13 (4B2)
/DISP_MOSI: J401.16, U602.3 (1B2)
/DISP_SCK: J401.15, U602.10 (3B2)
/ETH_LED0: J501.11 (LLED+), U801.3 (LED1/REGOFF)
/ETH_RXN: C814.1, J501.6 (RD-), R806.2, U801.22 (RXN)
/ETH_RXP: C813.1, J501.3 (RD+), R805.2, U801.23 (RXP)
/ETH_TXN: C812.2, J501.2 (TD-), R804.2, U801.20 (TXN)
/ETH_TXP: C811.2, J501.1 (TD+), R803.2, U801.21 (TXP)
/EXP_PWR_EN: R510.2, U301.116 (PF6), U505.1 (B)
/FRONT_ENC_A: J401.7, U301.18 (PA6)
/FRONT_ENC_B: J401.6, U301.17 (PA4)
/FRONT_SCL: J401.11, R402.1, U601.6 (SCL0)
/FRONT_SDA: J401.12, R403.1, U601.5 (SDA0)
/IO_SCL: R603.1, U101.2 (SCL), U502.8 (SMCLK), U601.10 (SCL1), U802.6 (SCL)
/IO_SDA: R604.1, U101.1 (SDA), U502.7 (SMDATA), U601.9 (SDA1), U802.5 (SDA)
/LCD_B0: J401.20, U301.21 (PD9)
/LCD_B1: J401.21, U301.22 (PG12)
/LCD_B2: J401.22, U301.23 (PG10)
/LCD_B3: J401.23, U301.24 (PD10)
/LCD_B4: J401.24, U301.25 (PI4)
/LCD_B5: J401.25, U301.26 (PI5)
/LCD_B6: J401.26, U301.27 (PI6)
/LCD_B7: J401.27, U301.28 (PI7)
/LCD_DE: J401.47, U301.48 (PE13)
/LCD_G0: J401.29, U301.30 (PE14)
/LCD_G1: J401.30, U301.31 (PE6)
/LCD_G2: J401.31, U301.32 (PH13)
/LCD_G3: J401.32, U301.33 (PH14)
/LCD_G4: J401.33, U301.34 (PH15)
/LCD_G5: J401.34, U301.35 (PI0)
/LCD_G6: J401.35, U301.36 (PI1)
/LCD_G7: J401.36, U301.37 (PI2)
/LCD_HSYNC: J401.49, U301.50 (PI10)
/LCD_PCLK: J401.48, U301.51 (PG7)
/LCD_PWM: J401.18, U301.19 (PB7)
/LCD_R0: J401.38, U301.40 (PH2)
/LCD_R1: J401.39, U301.41 (PH3)
/LCD_R2: J401.40, U301.42 (PH8)
/LCD_R3: J401.41, U301.43 (PH9)
/LCD_R4: J401.42, U301.44 (PH10)
/LCD_R5: J401.43, U301.45 (PH11)
/LCD_R6: J401.44, U301.46 (PH12)
/LCD_R7: J401.45, U301.47 (PE15)
/LCD_VSYNC: J401.50, U301.49 (PI9)
/Power Supply/3V3_ENABLE: PS201.10 (ON/OFF), R204.2, U201.2 (~RESET)
/Power Supply/AC+: D205.3, R207.2, X201.5
/Power Supply/AC-: D205.2, R208.2, X201.8
/Power Supply/ACIN_L: J201.4, RV201.1, SW201.P_{1} (B)
/Power Supply/ACIN_N: J201.1, RV201.2, SW201.P_{2} (B)
/Rear IO Connections/FAN_PWM: Q501.1 (B), U502.4 (FAN)
/Rear IO Connections/FAN_TACH: R502.2, R503.2, R509.2, U502.6 (TACH)
/TRIGGER: U301.88 (PG8), U507.4
/USBD_DN: U301.105 (USB2N), U501.6
/USBD_DP: U301.104 (USB2P), U501.1
/USBH_DN: U301.108 (USB1N), U401.6
/USBH_DP: U301.107 (USB1P), U401.1
/ZERO_CROSS: R209.2, U202.4, U301.127 (PF10)
/~ANA_IRQ: J701.10, R703.1, U301.58 (PG3)
/~ANA_RESET: J701.11, U301.57 (PD8)
/~DISP_CS: J401.14, R407.1, U301.134 (PC8/MMC1_D0), U603.1
/~ETH_LED1: R506.1, U801.2 (LED2/nINTSEL)
/~FRONT_IRQ: J401.10, R404.1, U601.4 (~INT0)
/~FRONT_RESET: J401.9, R401.1, U301.16 (PB9)
GND: BT301.2 (-), C101.1, C201.1, C202.1, C203.2, C204.1, C205.1, C206.1, C207.2, C212.2, C213.2, C214.2, C301.2, C302.2, C305.2, C401.1, C402.2, C403.2, C501.1, C502.2, C503.1, C505.1, C601.2, C602.2, C701.1, C702.2, C801.2, C802.2, C803.2, C804.2, C805.2, C806.2, C807.2, C808.2, C809.2, C810.1, C811.1, C812.1, C813.2, C814.2, C901.2, C902.2, C903.2, C904.2, C905.2, C906.2, D201.1 (K), D202.1 (K), D203.1 (K), D204.2 (A2), D205.4 (-), D206.1 (K), D501.3 (common), D504.1 (K), J301.3 (GND), J301.5 (GND), J301.9 (GNDDetect), J302.5, J401.5, J401.8, J401.13, J401.19, J401.28, J401.37, J401.46, J402.4 (GND), J502.4 (GND), J503.2, J701.7, J701.13, J701.14, J701.17, J701.18, JP301.1 (A), M501.1 (-), PS201.3 (GND), PS201.7 (GND), PS202.3 (GND), PS202.7 (GND), PS203.2 (GND), Q401.2 (E), Q501.2 (E), R204.1, R205.2, R308.1, R502.1, R505.1, R510.1, R512.1, R801.2, RV202.1, RV501.2, RV501.3, SW302.2, TP204.1, U101.4 (GND), U101.5 (A2), U101.6 (A1), U101.7 (A0), U201.1 (GND), U202.3, U301.1 (GND), U301.8 (GND), U301.20 (GND), U301.29 (GND), U301.38 (GND), U301.39 (GND), U301.52 (GND), U301.61 (GND), U301.74 (GND), U301.75 (GND), U301.89 (GND), U301.96 (GND), U301.103 (GND), U301.106 (GND), U301.109 (GND), U301.112 (GND), U301.113 (GND), U301.124 (GND), U301.133 (GND), U301.140 (GND), U301.148 (GND), U401.2 (GND), U501.2 (GND), U502.5 (GND), U503.3, U505.2 (E), U507.3 (GND), U601.1 (A0), U601.2 (A1), U601.7 (GND), U602.8 (GND), U603.2 (GND), U603.6, U801.25 (VSS), U802.1 (A_{0}), U802.2 (A_{1}), U802.3 (A_{2}), U802.4 (GND), U901.9 (VSS), U902.2 (GND), Y901.2, Y901.4
GND2: H103.1, J501.8, J501.S1 (SHIELD), J501.S2 (SHIELD), J502.5 (Shield), R205.1
LINE: SW201.R_{1} (C), X201.4
NEUT: SW201.R_{2} (C), X201.1
unnamed: C504.1, RV501.1, TP501.1, U507.2
unnamed: C504.2, R512.2, U506.3
unnamed: C701.2, F702.1, FB701.2
unnamed: D201.2 (A), R201.2
unnamed: D202.2 (A), R202.2
unnamed: D203.2 (A), R203.2
unnamed: D206.2 (A), R206.2
unnamed: D207.2 (A), R208.1, U202.2
unnamed: D207.1 (K), R207.1, U202.1
unnamed: D301.4 (BK), R303.2
unnamed: D301.3 (GK), R302.2
unnamed: D301.2 (RK), R301.2
unnamed: D302.3, R306.1
unnamed: D303.1 (A1), R307.2
unnamed: D303.4 (K2), R308.2
unnamed: D401.2 (A), LS401.2, Q401.3 (C)
unnamed: D501.1 (A1), J503.4, L501.1
unnamed: D501.2 (A2), J503.3, L501.2
unnamed: D502.2 (A), K501.5, R513.2
unnamed: D502.1 (K), F501.2
unnamed: D503.2 (A), J504.2, U506.2
unnamed: D503.1 (K), R511.1, U506.1
unnamed: F401.2, FB401.1
unnamed: F402.1, FB402.2
unnamed: F501.1, FB501.2
unnamed: J201.2, X201.2
unnamed: J201.3, X201.3
unnamed: FB401.2, J401.1, J401.2, J401.3, J401.4
unnamed: J402.3 (D+), U401.3
unnamed: J402.2 (D-), U401.4
unnamed: FB402.1, J402.1 (VBUS), U401.5 (VBUS)
unnamed: C503.2, FB502.2, J501.4 (CT), J501.5 (CT)
unnamed: J501.12 (LLED-), R505.2
unnamed: J501.10 (RLED-), R506.2
unnamed: J502.3 (D+), U501.3
unnamed: J502.2 (D-), U501.4
unnamed: J502.1 (VBUS), U501.5 (VBUS)
unnamed: FB501.1, J503.1
unnamed: J504.1, R511.2
unnamed: F701.2, J701.15, J701.16
unnamed: FB701.1, J701.19, J701.20
unnamed: LS401.1, R405.1
unnamed: M501.4 (PWM), Q501.3 (C), R501.1
unnamed: M501.3 (Tacho), R503.1, R504.1
unnamed: F202.2, PS201.1 (+VIN), PS201.2 (+VIN)
unnamed: F203.2, PS202.1 (+VIN), PS202.2 (+VIN)
unnamed: Q401.1 (B), R406.2
unnamed: R507.1, U503.1
unnamed: R508.1, U503.6
unnamed: D504.2 (A), R513.1
unnamed: RN802.1 (R1.1), U801.11 (CRS_DV/MODE2)
unnamed: RN802.2 (R2.1), U801.8 (RXD0/MODE0)
unnamed: RN802.4 (R4.1), U801.7 (RXD1/MODE1)
unnamed: K501.12, U504.2 (A), U505.3 (C)
unnamed: R801.1, U801.24 (RBIAS)
unnamed: RN801.2 (R2.1), U801.17 (TXD0)
unnamed: RN801.1 (R1.1), U801.18 (TXD1)
unnamed: RN801.3 (R3.1), U801.16 (TXEN)
unnamed: C802.1, C803.1, U801.6 (VDDCR)
unnamed: R808.2, U801.5 (XTAL1/CLKIN)
unnamed: X201.6, X201.7
VBUS: C201.2, C202.2, C204.2, C205.2, C212.1, C213.1, D204.1 (A1), D205.1 (+), F202.1, F203.1, PS203.1 (+VIN), R206.1, RV202.2

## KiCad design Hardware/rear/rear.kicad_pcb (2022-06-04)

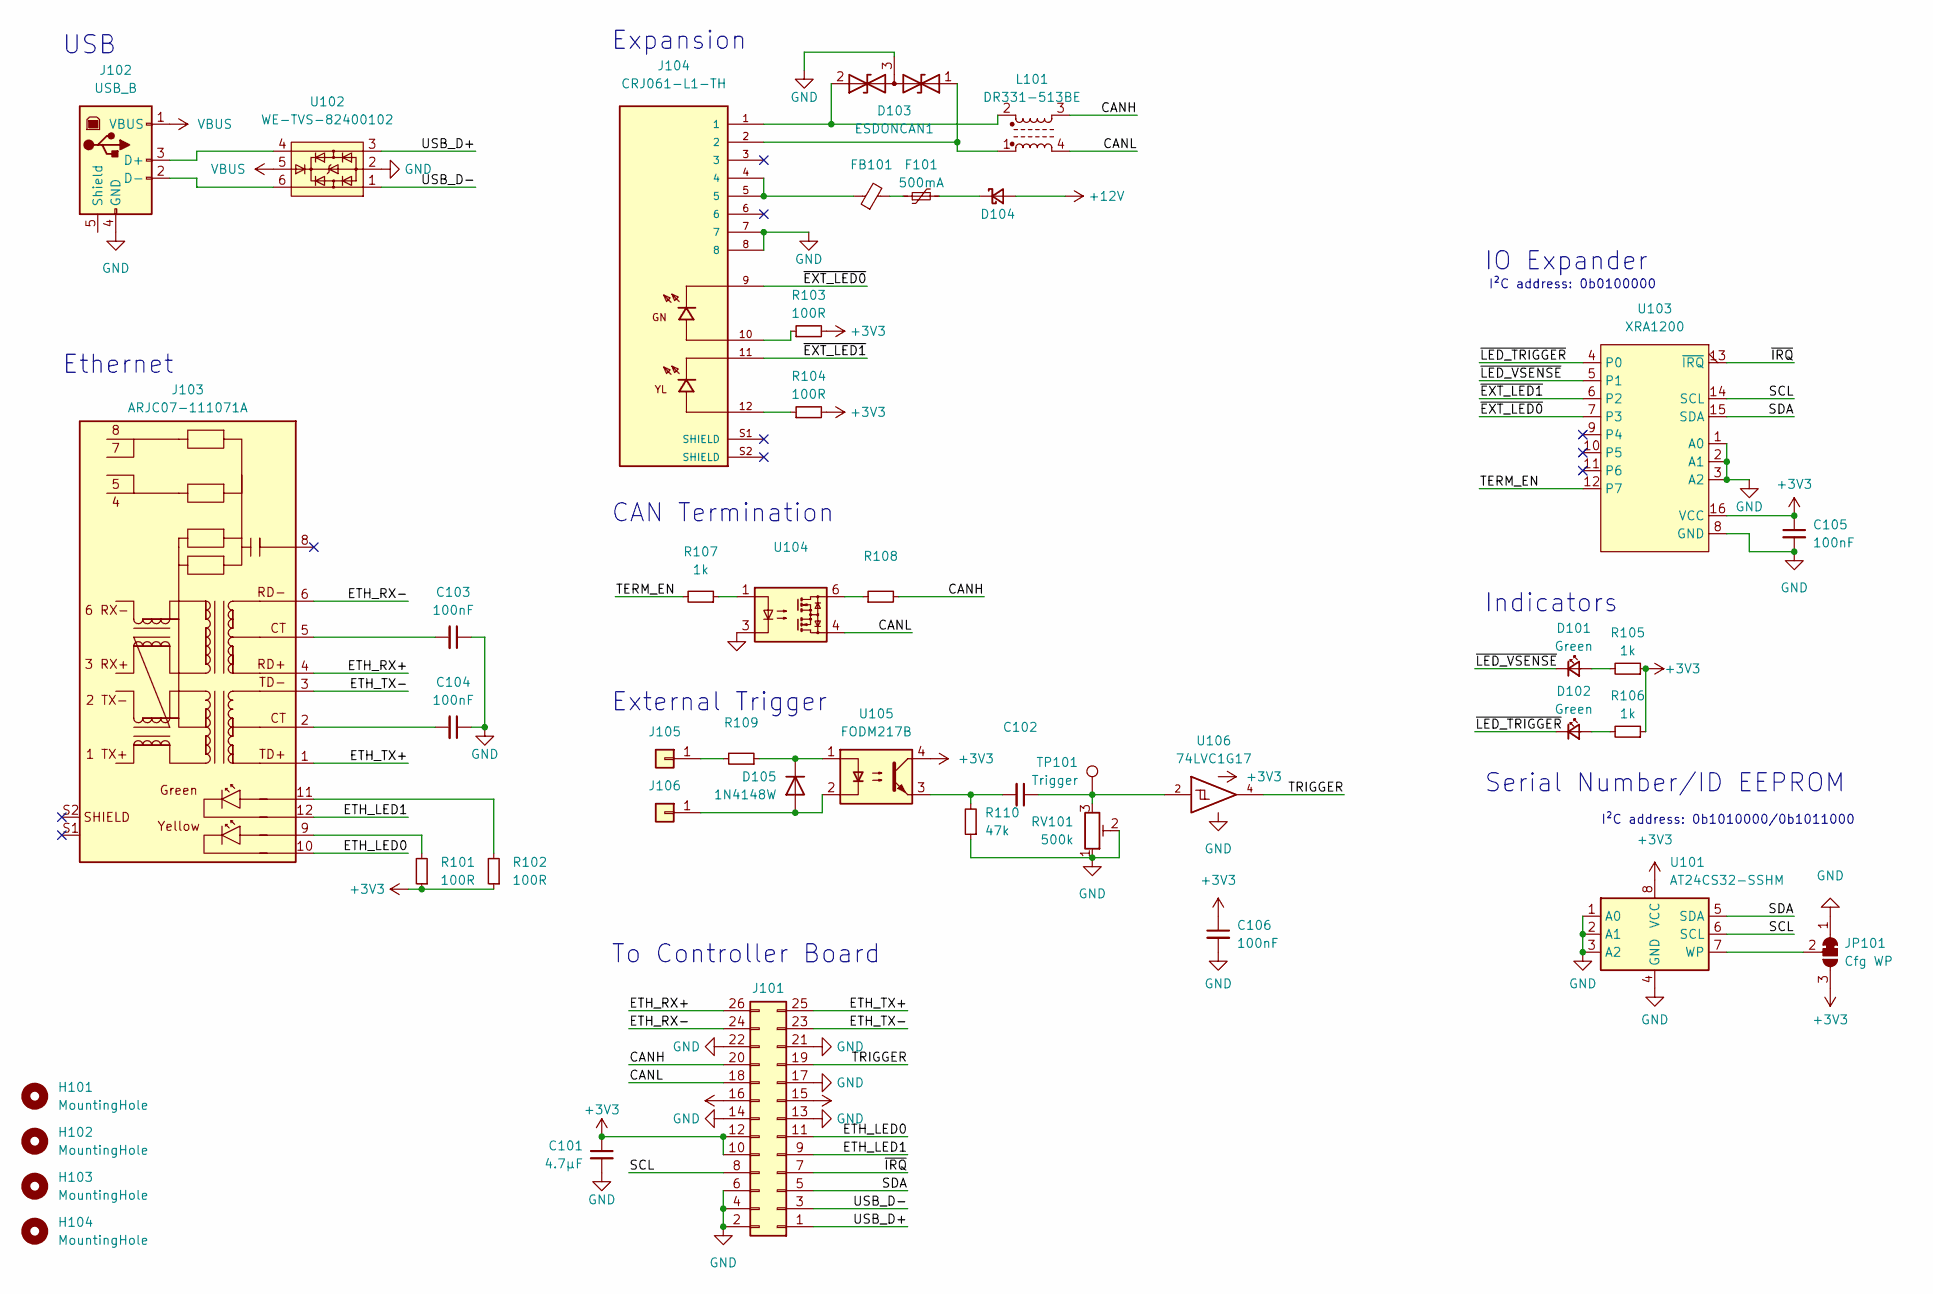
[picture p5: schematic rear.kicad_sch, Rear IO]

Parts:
C101: 4.7µF; C_0805_2012Metric_Pad1.18x1.45mm_HandSolder; MPN CL21A475KAQNNNF
C102: MPN CL21B105KBFNNNG
C103, C104, C105: 100nF; C_0805_2012Metric_Pad1.18x1.45mm_HandSolder; MPN CL21B104KACNFNC
C106: 100nF; C_0805_2012Metric_Pad1.18x1.45mm_HandSolder
D101, D102: Green; LED_0805_2012Metric_Pad1.15x1.40mm_HandSolder
D103: ESDONCAN1; SOT-23_Handsoldering; MPN ESDONCAN1LT1G
D104: Panjit SS14; D_SMA_Handsoldering; MPN SS14_R1_00001
D105: 1N4148W; D_SOD-123; MPN 1N4148W-AU_R1_000A1
F101: 500mA; Fuse_1206_3216Metric_Pad1.42x1.75mm_HandSolder; MPN 0ZCJ0050FF2G
FB101: FerriteBead_Small; L_0805_2012Metric_Pad1.05x1.20mm_HandSolder; MPN MFBM1V2012-800-R
H101, H102, H103, H104: MountingHole; MountingHole_2.7mm_M2.5
J101: Conn_02x10_Odd_Even; PinHeader_2x13_P1.27mm_Vertical; MPN 20021111-00026T4LF
J102: USB_B; USB_B_TE_5787834_Vertical_ShieldSplit; MPN 5787834-2
J103: ARJC07-111071A; ABRACON-ARJC07-111071A; MPN ARJC07-111071A
J104: CRJ061-L1-TH; CUI_CRJ061-L1-TH; PARTREV 1.0
J105: MPN 2108-2-00-01-00-00-07-0
J106: Conn_01x01; MillMax-2108-2; MPN 2108-2-00-01-00-00-07-0
JP101: Cfg WP; SolderJumper-3_P1.3mm_Bridged12_RoundedPad1.0x1.5mm
L101: DR331-513BE; Bourns-DR331-0-0-MFG; MPN DR331-513BE
R101, R102, R103, R104: 100R; R_0805_2012Metric_Pad1.20x1.40mm_HandSolder; MPN WR08X101 JTL
R105, R106, R107: 1k; R_0805_2012Metric_Pad1.20x1.40mm_HandSolder; MPN CR0805-JW-102ELF
R108: MPN RMC1/4-101JTE
R109: MPN 260-200-RC
R110: 47k; R_0805_2012Metric_Pad1.20x1.40mm_HandSolder; MPN RMC1/10-473JTP
RV101: 500k; Potentiometer_Nidec_Copal_CT94EW; MPN CT-94EW504
TP101: Trigger; TestPoint_Keystone_5000-5004_Miniature; MPN 5004
U101: AT24CS32-SSHM; SOIC-8_3.9x4.9mm_P1.27mm; MPN AT24CS32-SSHM
U102: WE-TVS-82400102; SOT-23-6; MPN 82400102
U103: XRA1200; TSSOP-16_4.4x5mm_P0.65mm
U104: (no value)
U105: FODM217B; SOP-4_4.4x2.6mm_P1.27mm; MPN FODM217B
U106: 74LVC1G17; SOT-23-5_HandSoldering; MPN SN74LVC1G17DBVRG4

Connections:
+3V3: C101.1, C105.1, C106.1, J101.10, J101.12, JP101.3 (B), R101.1, R102.1, R103.2, R104.2, R105.1, R106.1, U101.8 (VCC), U103.16 (VCC), U105.4, U106.5 (VCC)
/CANH: J101.20, L101.3, R108.2
/CANL: J101.18, L101.4, U104.4
/ETH_LED0: J101.11, J103.10 (RLED-)
/ETH_LED1: J101.9, J103.12 (LLED-)
/ETH_RX+: J101.26, J103.4 (RD+)
/ETH_RX-: J101.24, J103.6 (RD-)
/ETH_TX+: J101.25, J103.1 (TD+)
/ETH_TX-: J101.23, J103.3 (TD-)
/SCL: J101.8, U101.6 (SCL), U103.14 (SCL)
/SDA: J101.5, U101.5 (SDA), U103.15 (SDA)
/TERM_EN: R107.2, U103.12 (P7)
/TRIGGER: J101.19, U106.4
/USB_D+: J101.1, U102.3
/USB_D-: J101.3, U102.1
/~EXT_LED0: J104.9, U103.7 (P3)
/~EXT_LED1: J104.11, U103.6 (P2)
/~IRQ: J101.7, U103.13 (~IRQ)
/~LED_TRIGGER: D102.1 (K), U103.4 (P0)
/~LED_VSENSE: D101.1 (K), U103.5 (P1)
unnamed: C102.1, RV101.3, TP101.1, U106.2
unnamed: C103.2, J103.5 (CT)
unnamed: C104.2, J103.2 (CT)
unnamed: D101.2 (A), R105.2
unnamed: D102.2 (A), R106.2
unnamed: D103.1 (A1), J104.2, L101.1
unnamed: D103.2 (A2), J104.1, L101.2
unnamed: D104.1 (K), F101.2
unnamed: D105.1 (K), R109.1, U105.1
unnamed: F101.1, FB101.2
unnamed: FB101.1, J104.4, J104.5
unnamed: J102.2 (D-), U102.6
unnamed: J102.3 (D+), U102.4
unnamed: J103.9 (RLED+), R101.2
unnamed: J103.11 (LLED+), R102.2
unnamed: J104.10, R103.1
unnamed: J104.12, R104.1
unnamed: J105.1, R109.2
unnamed: D105.2 (A), J106.1, U105.2
unnamed: JP101.2 (C), U101.7 (WP)
unnamed: R107.1, U104.1
unnamed: R108.1, U104.6
unnamed: C102.2, R110.2, U105.3
VBUS: J102.1 (VBUS), U102.5

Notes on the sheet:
IO Expander
USB
Ethernet
I²C address: 0b1010000/0b1011000
External Trigger
To Controller Board
CAN Termination
Indicators
Expansion
I²C address: 0b0100000
Serial Number/ID EEPROM

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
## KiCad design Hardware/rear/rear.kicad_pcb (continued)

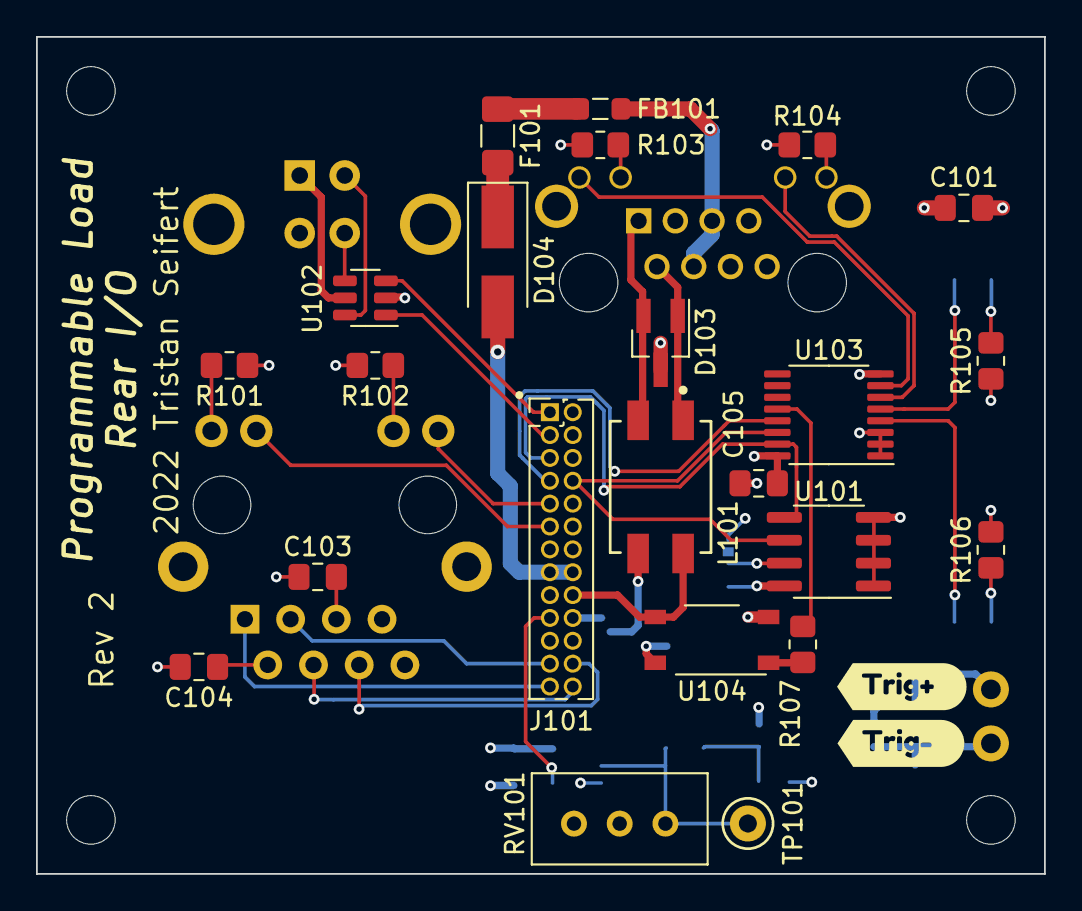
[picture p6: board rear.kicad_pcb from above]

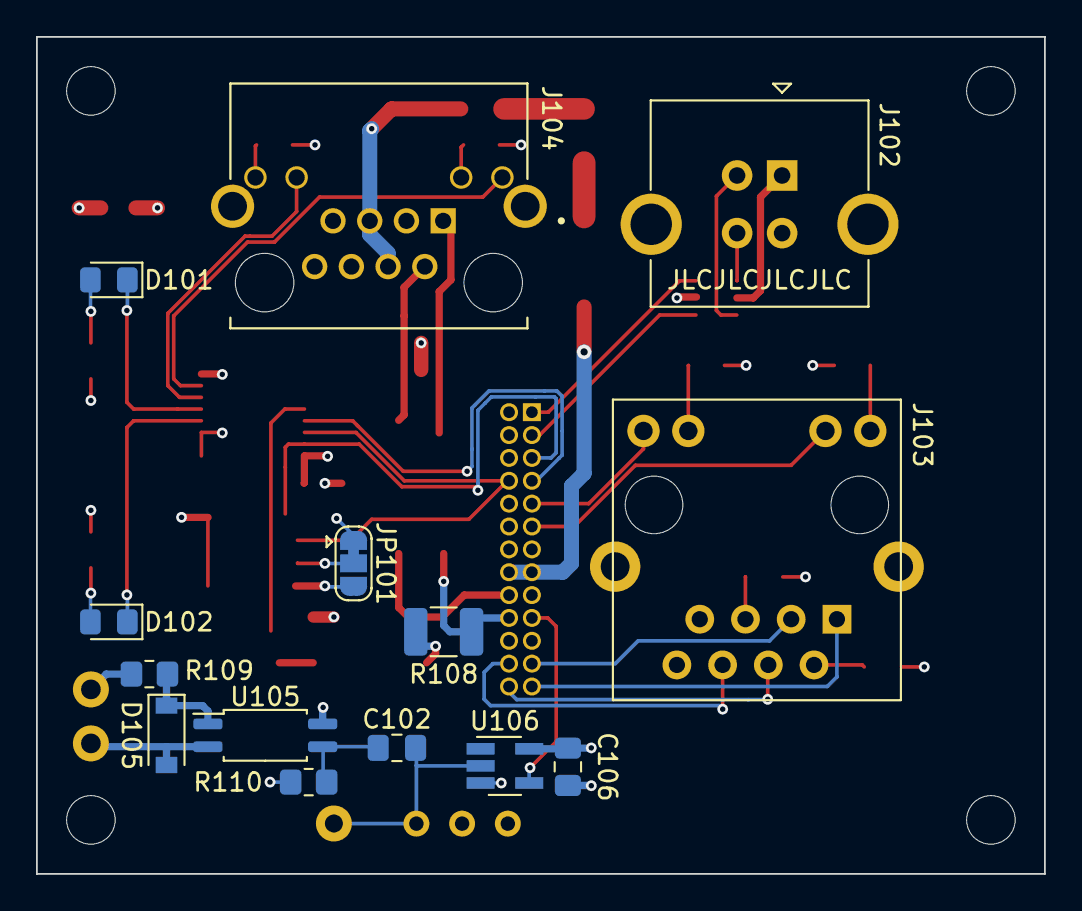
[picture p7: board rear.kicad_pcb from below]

Board: 4 copper layers, 56.0 x 46.5 mm, 45 parts (14 on the bottom side), 46 nets.

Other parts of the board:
kibuzzard-62664110: G***; kibuzzard-62664110
kibuzzard-62664123: G***; kibuzzard-62664123

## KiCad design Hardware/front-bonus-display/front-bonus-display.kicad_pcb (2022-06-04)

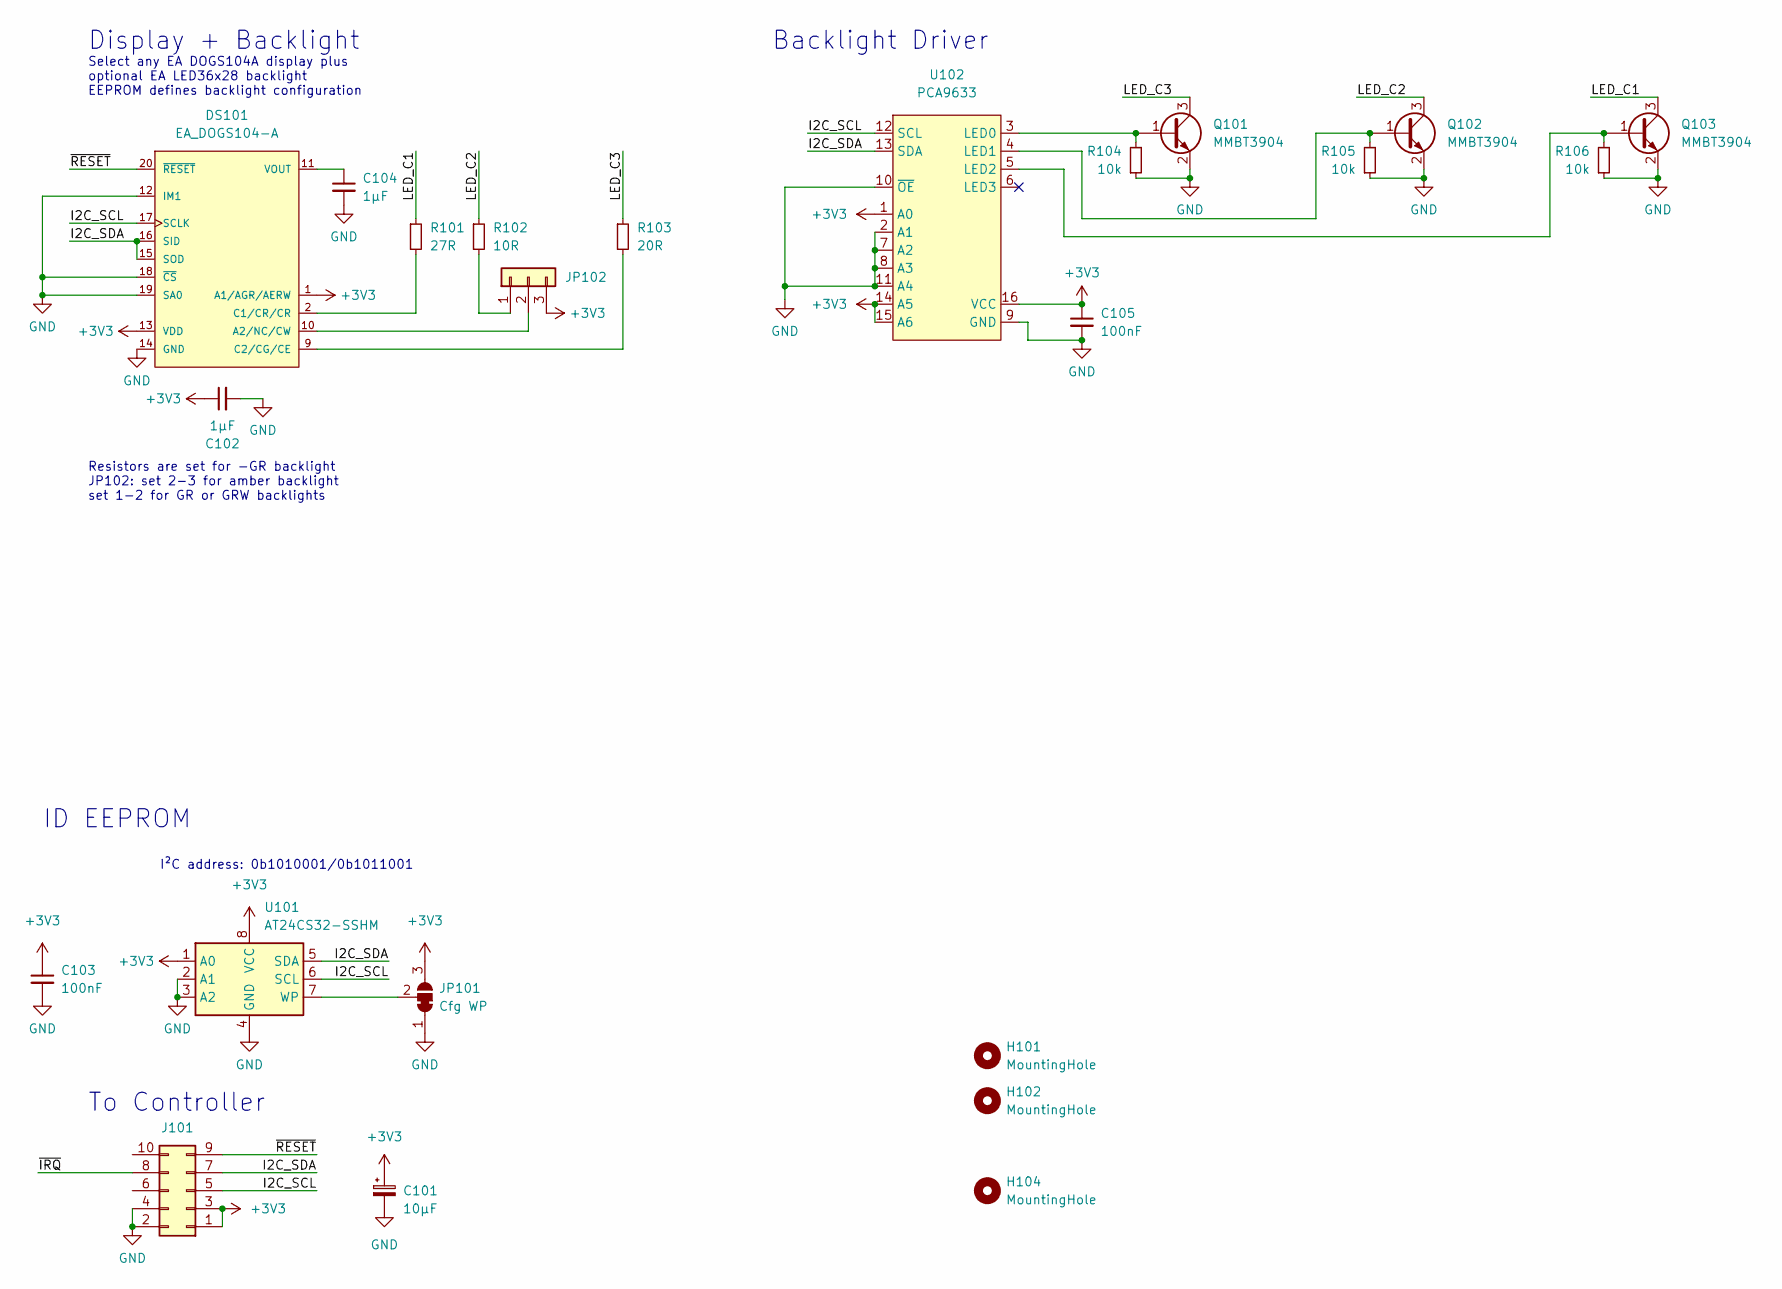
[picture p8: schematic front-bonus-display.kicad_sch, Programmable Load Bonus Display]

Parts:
C101: 10µF; CP_EIA-3216-18_Kemet-A_Pad1.58x1.35mm_HandSolder; MPN TAJA106K016RNJ
C102, C104: 1µF; C_0805_2012Metric_Pad1.18x1.45mm_HandSolder; MPN CL21B105KBFNNNG
C103, C105: 100nF; C_0805_2012Metric_Pad1.18x1.45mm_HandSolder
DS101: EA_DOGS104-A; Display_Visions-EA_DOGS104-A-BACKLIGHT-SOCKET; MPN EA DOGS104W-A
H101, H102, H104: MountingHole; MountingHole_2.7mm_M2.5
J101: Conn_02x05_Odd_Even; PinHeader_2x05_P1.27mm_Vertical_SMD
JP101: Cfg WP; SolderJumper-3_P1.3mm_Bridged12_RoundedPad1.0x1.5mm_NumberL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
JP102: Jumper_3_Open; PinHeader_1x03_P2.54mm_Vertical; MPN G800W305018EU
Q101, Q102, Q103: MMBT3904; SOT-323_SC-70_Handsoldering; MPN MMBT3904,215
R101: 27R; R_0805_2012Metric_Pad1.20x1.40mm_HandSolder; MPN ERJ-P06J270V
R102: 10R; R_0805_2012Metric_Pad1.20x1.40mm_HandSolder; MPN ERJ-P06J100V
R103: 20R; R_0805_2012Metric_Pad1.20x1.40mm_HandSolder; MPN ERJ-P06J200V
R104, R105, R106: 10k; R_0805_2012Metric_Pad1.20x1.40mm_HandSolder; MPN RMC1/10-103JTP
U101: AT24CS32-SSHM; SOIC-8_3.9x4.9mm_P1.27mm
U102: PCA9633; TSSOP-16_4.4x5mm_P0.65mm

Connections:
+3V3: C101.1, C102.1, C103.1, C105.1, DS101.1 (A1/AGR/AERW), DS101.13 (VDD), J101.1, J101.3, JP101.3 (B), JP102.3, U101.1 (A0), U101.8 (VCC), U102.1 (A0), U102.14 (A5), U102.15 (A6), U102.16 (VCC)
/I2C_SCL: DS101.17 (SCLK), J101.5, U101.6 (SCL), U102.12 (SCL)
/I2C_SDA: DS101.15 (SOD), DS101.16 (SID), J101.7, U101.5 (SDA), U102.13 (SDA)
/LED_C1: Q103.3 (C), R101.1
/LED_C2: Q102.3 (C), R102.1
/LED_C3: Q101.3 (C), R103.1
/~IRQ: J101.8
/~RESET: DS101.20 (~RESET), J101.9
GND: C101.2, C102.2, C103.2, C104.2, C105.2, DS101.12 (IM1), DS101.14 (GND), DS101.18 (~CS), DS101.19 (SA0), J101.2, J101.4, JP101.1 (A), Q101.2 (E), Q102.2 (E), Q103.2 (E), R104.1, R105.1, R106.1, U101.2 (A1), U101.3 (A2), U101.4 (GND), U102.2 (A1), U102.7 (A2), U102.8 (A3), U102.9 (GND), U102.10 (~OE), U102.11 (A4)
unnamed: C104.1, DS101.11 (VOUT)
unnamed: DS101.2 (C1/CR/CR), R101.2
unnamed: DS101.9 (C2/CG/CE), R103.2
unnamed: DS101.10 (A2/NC/CW), JP102.2
unnamed: JP101.2 (C), U101.7 (WP)
unnamed: JP102.1, R102.2
unnamed: Q101.1 (B), R104.2, U102.3 (LED0)
unnamed: Q102.1 (B), R105.2, U102.4 (LED1)
unnamed: Q103.1 (B), R106.2, U102.5 (LED2)

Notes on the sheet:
Resistors are set for -GR backlight JP102: set 2-3 for amber backlight set 1-2 for GR or GRW backlights
ID EEPROM
Display + Backlight
Select any EA DOGS104A display plus optional EA LED36x28 backlight EEPROM defines backlight configuration
I²C address: 0b1010001/0b1011001
Backlight Driver
To Controller

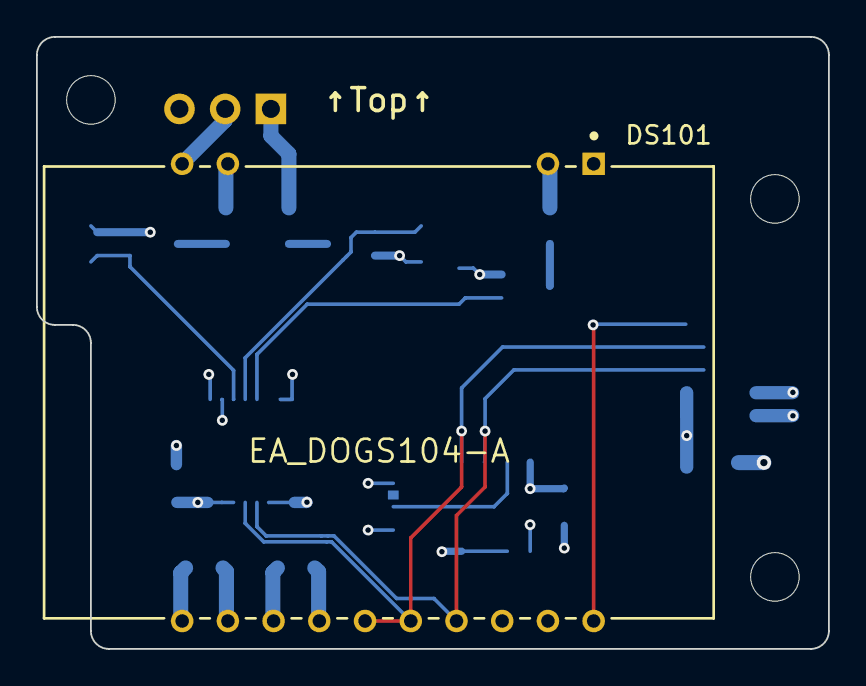
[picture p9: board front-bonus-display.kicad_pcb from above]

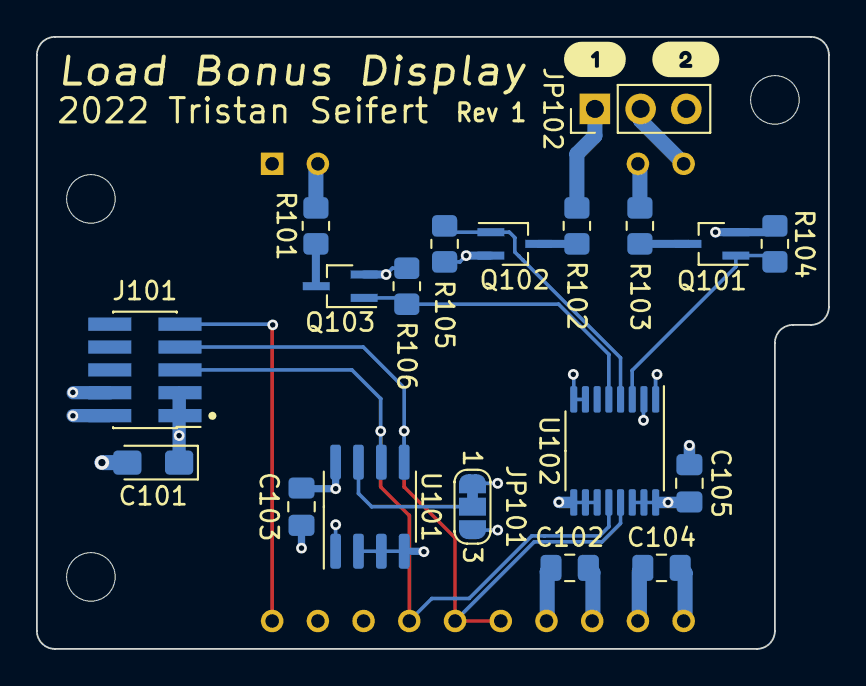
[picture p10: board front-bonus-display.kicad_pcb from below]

Board: 4 copper layers, 44.0 x 34.0 mm, 25 parts (21 on the bottom side), 17 nets.

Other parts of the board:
kibuzzard-627F235A: G***; kibuzzard-627F235A
kibuzzard-627F2330: G***; kibuzzard-627F2330

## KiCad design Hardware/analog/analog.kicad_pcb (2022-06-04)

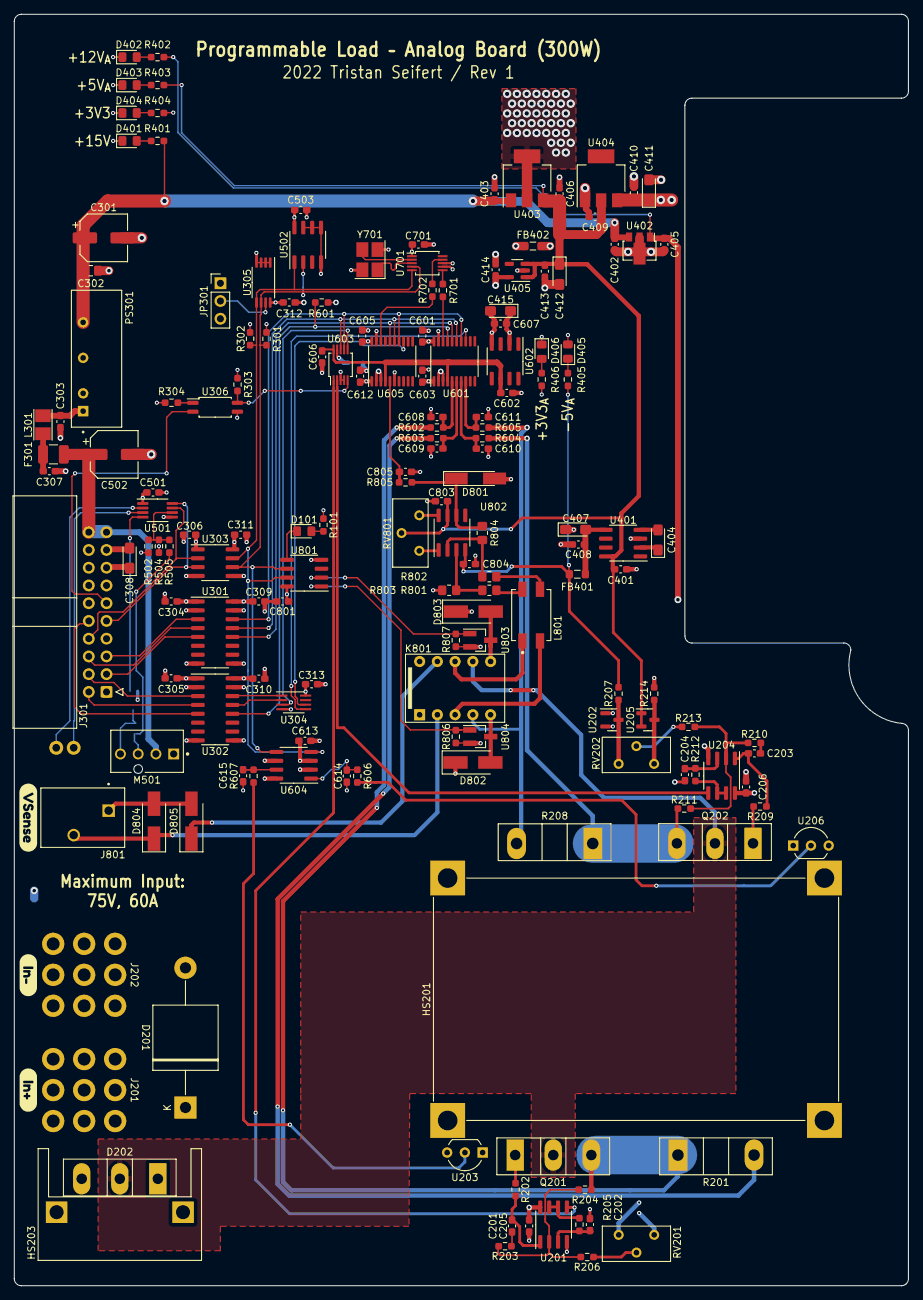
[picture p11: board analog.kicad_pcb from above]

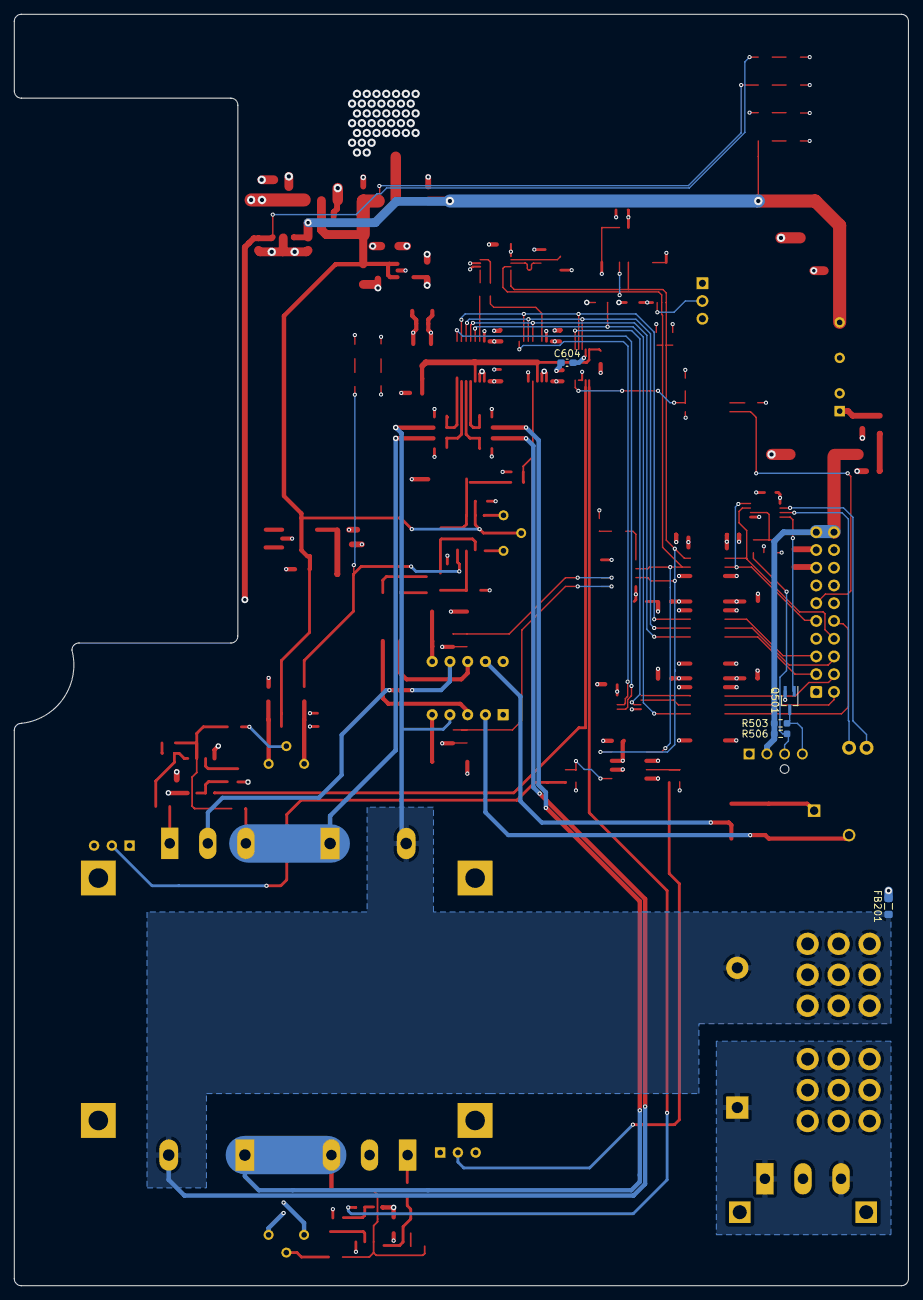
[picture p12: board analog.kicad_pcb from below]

Board: 4 copper layers, 128.0 x 182.0 mm, 174 parts (5 on the bottom side), 108 nets.

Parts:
C201, C203: 1nF; C_0603_1608Metric_Pad1.08x0.95mm_HandSolder
C202, C204: 22nF; C_0603_1608Metric_Pad1.08x0.95mm_HandSolder
C205, C206, C304, C305, C306, C309, C310, C311, C312, C313, C408, C501, C503, C601, C603, C604, C605, C607, C608, C609, C610, C611, C612, C613, C614, C615, C701, C801, C803, C804, C805: 100nF; C_0603_1608Metric_Pad1.08x0.95mm_HandSolder
C301, C502: 33µF; CP_Elec_6.3x5.7
C302: 10µF; C_0805_2012Metric_Pad1.18x1.45mm_HandSolder
C303, C307, C401, C402, C403, C405, C406, C409, C410, C413, C414, C602, C606: 4.7µF; C_0603_1608Metric_Pad1.08x0.95mm_HandSolder
C308, C404, C407, C411, C412, C415: 10µF; CP_EIA-3216-18_Kemet-A_Pad1.58x1.35mm_HandSolder
D101: Red; LED_0805_2012Metric_Pad1.15x1.40mm_HandSolder
D201: 5KP78A; D_P600_R-6_P20.00mm_Horizontal
D202: DSA120C150QB; TO-247-3_Vertical
D401, D402, D403, D404, D405, D406: Green; LED_0805_2012Metric_Pad1.15x1.40mm_HandSolder
D801: 2V4; D_MiniMELF_Handsoldering
D802, D803: SM4007; D_SMA_Handsoldering
D804: 75V; D_SMA_Handsoldering
D805: SS110; D_SMA_Handsoldering
F301: 350mA; Fuse_1210_3225Metric_Pad1.42x2.65mm_HandSolder
FB201, FB401, FB402: FerriteBead_Small; L_0805_2012Metric_Pad1.05x1.20mm_HandSolder
HS201: 2x C40-058-AE; C40-058-AE-DUAL
HS203: WV-T247-101E; Ohmite-WA-T247-101E-MFG
J201, J202: Würth 74651194R; WE-74651194
J301: Conn_02x10_Odd_Even; IDC-Header_2x10_P2.54mm_Horizontal
J501, J502: Conn_01x01; MillMax-2108-2
J801: Conn_01x02; CUI_TBL002A-350-02GR-2OR
JP301: Cfg WP; PinHeader_1x03_P2.54mm_Vertical
K801: EA2-3T; KEMET-EA2
L301: 6.8µH; L_Taiyo-Yuden_NR-24xx_HandSoldering
L801: L_Ferrite_Coupled_1423; Bourns-DR331-0-0-MFG
M501: Fan_4pin; Molex-47053-1000-MFG
PS301: PCN2-S12-S15-S; CONV_PCN2-S12-S15-S
Q201, Q202: IXTH80N075L2; TO-247-3_Vertical
Q501: MMBT3904; SOT-323_SC-70_Handsoldering
R101, R203, R204, R207, R210, R211, R214, R404, R406, R602, R603, R604, R605: 1k; R_0603_1608Metric_Pad0.98x0.95mm_HandSolder
R201, R208: .05R; TO-247-2_Vertical
R202, R209: 100R; R_0603_1608Metric_Pad0.98x0.95mm_HandSolder
R205, R212, R402, R805: 4k99; R_0603_1608Metric_Pad0.98x0.95mm_HandSolder
R206, R213: 330k (?); R_0603_1608Metric_Pad0.98x0.95mm_HandSolder
R301, R302, R403, R405: 2k2; R_0603_1608Metric_Pad0.98x0.95mm_HandSolder
R303, R504, R601: 10k; R_0603_1608Metric_Pad0.98x0.95mm_HandSolder
R304: 200R; R_0603_1608Metric_Pad0.98x0.95mm_HandSolder
R401: 7k5; R_0603_1608Metric_Pad0.98x0.95mm_HandSolder
R502: 5k6; R_0603_1608Metric_Pad0.98x0.95mm_HandSolder
R503, R506, R806, R807: 4k7; R_0603_1608Metric_Pad0.98x0.95mm_HandSolder
R505: 27k4; R_0603_1608Metric_Pad0.98x0.95mm_HandSolder
R606, R607: 27k1; R_0603_1608Metric_Pad0.98x0.95mm_HandSolder
R701, R702: 0R; R_0603_1608Metric_Pad0.98x0.95mm_HandSolder
R801, R802: 1M .1%; R_0805_2012Metric_Pad1.20x1.40mm_HandSolder
R803, R804: 20k .1%; R_0805_2012Metric_Pad1.20x1.40mm_HandSolder
RV201, RV202: 10k; Potentiometer_Nidec_Copal_CT94EY
RV801: 20k; Potentiometer_Nidec_Copal_CT94EY
U201, U204: ADA4522-2; SOIC-8_3.9x4.9mm_P1.27mm
U202, U205: LM431SC; SOT-23
U203, U206: LMT86LMT; TO-92_Inline_Wide
U301, U302: ADUM131D; SOIC-16_3.9x9.9mm_P1.27mm
U303: ADUM1250; SOIC-8_3.9x4.9mm_P1.27mm
U304: 74LVC1G139; SSOP-8_2.95x2.8mm_P0.65mm
U305: AT24CS32-SSHM; TSSOP-8_4.4x3mm_P0.65mm
U306: FODM217B; SOP-4_4.4x2.6mm_P1.27mm
U401: ICL7660; SOIC-8_3.9x4.9mm_P1.27mm
U402: MCP1804x-C002xMB; SOT-89-3
U403: MCP1703AT-5002E/DB; SOT-223-3_TabPin2
U404: XC6203E33; SOT-223
U405: LP5907MFX-3.3; SOT-23-5
U501: EMC2101-R; MSOP-8_3x3mm_P0.65mm
U502: LM75B; SOIC-8_3.9x4.9mm_P1.27mm
U601: MCP3562; TSSOP-20_4.4x6.5mm_P0.65mm
U602: MAX6166; SOIC-8_3.9x4.9mm_P1.27mm
U603: DAC8562; MSOP-10_3x3mm_P0.5mm
U604: MCP3426-xSN; SOIC-8_3.9x4.9mm_P1.27mm
U605: MCP3561; TSSOP-20_4.4x6.5mm_P0.65mm
U701: Si5351A-B-GT; MSOP-10_3x3mm_P0.5mm
U801: PCA9536D; SOIC-8_3.9x4.9mm_P1.27mm
U802: OPA277; SOIC-8_3.9x4.9mm_P1.27mm
U803, U804: MMBT3904; SOT-23_Handsoldering
Y701: 25MHz; Crystal_SMD_SeikoEpson_TSX3225-4Pin_3.2x2.5mm_HandSoldering
kibuzzard-6291C153: G***; kibuzzard-6291C153
kibuzzard-6280396F: G***; kibuzzard-6280396F
kibuzzard-62803980: G***; kibuzzard-62803980

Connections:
+3.3VP: C304.1, C305.1, C306.1, C308.1, C501.1, J301.15, J301.16, R304.2, R502.1, U301.1 (VCC_{1}), U302.1 (VCC_{1}), U303.1 (VDD1), U501.1 (VCC)
+3V3: C309.1, C310.1, C311.1, C312.1, C313.1, C410.1, C411.1, C503.1, C601.1, C605.1, C613.1, C701.1, C801.1, D802.1 (K), D803.1 (K), JP301.3 (B), K801.1, K801.10, R101.1, R301.2, R302.2, R303.1, R404.1, R601.2, U203.1 (Vdd), U206.1 (Vdd), U301.16 (VCC_{2}), U302.16 (VCC_{2}), U303.8 (VDD2), U304.8 (VCC), U305.8 (VCC), U404.3 (V_{out}), U502.8 (+Vs), U601.20 (D_{VCC}), U604.3 (VDD), U605.20 (D_{VCC}), U701.1 (VDD), U701.7 (VDDO), U801.8 (VDD)
+3V3A: C414.1, C415.1, C603.1, C604.1, C607.1, C612.1, R406.1, U405.5 (OUT), U601.1 (A_{VCC}), U602.2 (V_{in}), U603.9 (A_{VDD}), U605.1 (A_{VCC})
+5VA: C401.1, C406.1, C409.1, C412.1, C413.1, C803.1, R403.1, RV801.2, U205.1 (K), U205.2 (REF), U401.8 (V+), U403.3 (VO), U404.2 (V_{in}), U405.1 (IN), U405.3 (EN), U802.7 (V+)
+12VA: C205.2, C206.2, C405.1, R402.1, U201.8 (V+), U204.8 (V+), U402.1 (OUT)
+15V: C301.1, C302.1, C402.1, C403.1, PS301.6 (+Vout), R401.1, U402.3 (IN), U403.1 (VI)
+VDC: D202.2 (A), K801.7, Q201.2 (D), Q202.2 (D)
-5VA: C804.1, FB401.2, R207.2, R405.1, U802.4 (V-)
/Analog stuff/ADCCLK_{0}: R701.2, U601.18 (MCLK)
/Analog stuff/ADCCLK_{1}: R702.2, U605.18 (MCLK)
/Analog stuff/SPI_MISO: U301.12 (I_{C), U601.16 (MISO), U605.16 (MISO)
/Analog stuff/SPI_MOSI: U301.13 (O_{B), U601.15 (MOSI), U603.8 (MOSI), U605.15 (MOSI)
/Analog stuff/SPI_SCK: U301.14 (O_{A), U601.14 (SCK), U603.7 (SCLK), U605.14 (SCK)
/Analog stuff/Sense_{0+}: C608.1, R602.2, U601.5 (CH0)
/Analog stuff/Sense_{0-}: C609.2, R603.2, U601.6 (CH1)
/Analog stuff/Sense_{1+}: C610.1, R604.2, U601.7 (CH2)
/Analog stuff/Sense_{1-}: C611.2, R605.2, U601.8 (CH3)
/Analog stuff/TempSense_{0}: C614.1, R606.1, U604.1 (CH1+)
/Analog stuff/TempSense_{1}: C615.1, R607.1, U604.7 (CH2+)
/Analog stuff/VREF: C602.1, C606.1, U601.4 (REFIN+), U602.6 (V_{out}), U603.10 (VRef), U605.4 (REFIN+)
/Analog stuff/~CS_ADC_{0}: U304.5 (Y2), U601.13 (~CS)
/Analog stuff/~CS_ADC_{1}: U304.6 (Y1), U605.13 (~CS)
/Analog stuff/~CS_DAC: U304.3 (Y3), U603.6 (~SYNC)
/Analog stuff/~IRQ: R601.1, U302.12 (I_{C), U601.17 (~IRQ/MDAT)
/External Interface/IN_SPI_MOSI: J301.6, U301.4 (I_{B)
/External Interface/IN_SPI_SCK: J301.5, U301.3 (I_{A)
/External Interface/IN_SPI_SSEL0: J301.4, U302.3 (I_{A)
/External Interface/IN_SPI_SSEL1: J301.2, U302.4 (I_{B)
/External Interface/OUT_SPI_MISO: J301.3, U301.5 (O_{C)
/External Interface/SEL_0: U302.14 (O_{A), U304.1 (A)
/External Interface/SEL_1: U302.13 (O_{B), U304.2 (B)
/External Interface/~IN_RESET: J301.11, U306.2
/External Interface/~OUT_IRQ: J301.10, U302.5 (O_{C)
/External Interface/~RESET: R303.2, U306.4, U603.5 (~CLR)
/Fan Control & Temperature Sensors/FAN_PWM: Q501.1 (B), U501.4 (FAN)
/Fan Control & Temperature Sensors/FAN_TACH: R502.2, R504.2, R505.2, U501.6 (TACH)
/Fan Control & Temperature Sensors/TEMP_DN: J502.1, U501.3 (DN)
/Fan Control & Temperature Sensors/TEMP_DP: J501.1, U501.2 (DP)
/I2C_SCL: R301.1, U303.6 (SCL2), U305.6 (SCL), U502.2 (SCL), U604.5 (SCL), U701.4 (SCL), U801.6 (SCL)
/I2C_SDA: R302.1, U303.7 (SDA2), U305.5 (SDA), U502.1 (SDA), U604.4 (SDA), U701.5 (SDA), U801.7 (SDA)
/ISense_{0}: Q201.3 (S), R201.1, R204.2, R602.1
/ISense_{1}: Q202.3 (S), R208.1, R211.2, R604.1
/ISet_{0}: U201.5 (+), U603.1 (VOUT_{A})
/ISet_{1}: U204.5 (+), U603.2 (VOUT_{B})
/LED_STATUS: D101.1 (K), U801.5 (IO3)
/MOSFET Load/OffRef+: R214.1, RV201.3, RV202.3, U205.3 (A)
/MOSFET Load/OffRef-: R207.1, RV201.1, RV202.1, U202.3 (A)
/MOSFET Load/VBUS_IN: D201.1 (A1), D202.1 (K), D202.3 (K), J201.1
/TEMP_{0}: R606.2, U206.2 (OUT)
/TEMP_{1}: R607.2, U203.2 (OUT)
/VSense: C805.1, R805.1, U605.5 (CH0)
/Voltage Sense/EXT_SENSE+: D805.1 (K), K801.9
/Voltage Sense/EXT_SENSE-: D804.1 (A1), J801.2, K801.2
/Voltage Sense/IO_RLY_RESET: R807.2, U801.2 (IO1), U803.1 (B)
/Voltage Sense/IO_RLY_SET: R806.2, U801.1 (IO0), U804.1 (B)
/Voltage Sense/RELAY_RESET: D803.2 (A), K801.6, U803.3 (C)
/Voltage Sense/RELAY_SET: D802.2 (A), K801.5, U804.3 (C)
/Voltage Sense/VIN+: L801.4, R801.1
/Voltage Sense/VIN-: L801.3, R802.2
GND: C202.2, C204.2, C205.1, C206.1, C301.2, C302.2, C309.2, C310.2, C311.2, C312.2, C313.2, C401.2, C402.2, C403.2, C405.2, C406.2, C407.1, C408.2, C409.2, C410.2, C411.2, C412.2, C413.2, C503.2, C601.2, C605.2, C608.2, C609.1, C610.2, C611.1, C613.2, C614.2, C615.2, C701.2, C801.2, C803.2, C804.2, C805.2, D401.1 (K), D402.1 (K), D403.1 (K), D404.1 (K), D405.2 (A), D801.2 (A), FB201.2, FB402.1, JP301.1 (A), PS301.4 (-Vout), R214.2, R803.2, R806.1, R807.1, U201.4 (V-), U202.1 (K), U202.2 (REF), U203.3 (GND), U204.4 (V-), U206.3 (GND), U301.9 (GND_{2}), U301.15 (GND_{2}), U302.9 (GND_{2}), U302.15 (GND_{2}), U303.5 (GND2), U304.4 (GND), U305.1 (A0), U305.2 (A1), U305.3 (A2), U305.4 (GND), U306.3, U401.3 (GND), U402.2 (GND), U403.2 (GND), U404.1 (GND), U502.4 (GND), U502.5 (A2), U502.6 (A1), U502.7 (A0), U601.19 (D_{GND}), U604.2 (CH1-), U604.6 (VSS), U604.8 (CH2-), U605.19 (D_{GND}), U701.8 (GND), U801.4 (VSS), U803.2 (E), U804.2 (E), Y701.2, Y701.4
GND2: C303.2, C304.2, C305.2, C306.2, C307.2, C308.2, C501.2, C502.2, J301.7, J301.13, J301.14, J301.17, J301.18, M501.1 (-), PS301.2 (-Vin), Q501.2 (E), R504.1, U301.2 (GND_{1}), U301.8 (GND_{1}), U302.2 (GND_{1}), U302.8 (GND_{1}), U303.4 (GND1), U501.5 (GND)
GNDA: C414.2, C415.2, C602.2, C603.2, C604.2, C606.2, C607.2, C612.2, D406.1 (K), FB402.2, U405.2 (GND), U601.2 (A_{GND}), U601.3 (REFIN-), U602.4 (GND), U603.3 (GND), U603.4 (~{LDAC), U605.2 (A_{GND}), U605.3 (REFIN-), U605.6 (CH1)
GNDPWR: D201.2 (A2), FB201.1, J202.1, K801.4, R201.2, R208.2, R603.1, R605.1
IN_I2C_SCL: J301.9, U303.3 (SCL1), U501.8 (SMCLK)
IN_I2C_SDA: J301.8, U303.2 (SDA1), U501.7 (SMDATA)
unnamed: C201.1, R202.2, U201.1
unnamed: C201.2, R203.1
unnamed: C203.1, R209.2, U204.1
unnamed: C203.2, R210.1
unnamed: C307.1, F301.1, L301.2
unnamed: D101.2 (A), R101.2
unnamed: D401.2 (A), R401.2
unnamed: D402.2 (A), R402.2
unnamed: D403.2 (A), R403.2
unnamed: D404.2 (A), R404.2
unnamed: D405.1 (K), R405.2
unnamed: D406.2 (A), R406.2
unnamed: D801.1 (K), R804.1, R805.2, U802.6
unnamed: D804.2 (A2), D805.2 (A), J801.1
unnamed: JP301.2 (C), U305.7 (WP)
unnamed: K801.3, L801.2
unnamed: K801.8, L801.1
unnamed: M501.4 (PWM), Q501.3 (C), R503.1
unnamed: M501.3 (Tacho), R505.1, R506.1
unnamed: C303.1, L301.1, PS301.1 (+Vin)
unnamed: Q201.1 (G), R202.1
unnamed: Q202.1 (G), R209.1
unnamed: R206.1, RV201.2
unnamed: R213.1, RV202.2
unnamed: R304.1, U306.1
unnamed: C202.1, R205.1, U201.3 (+)
unnamed: R203.2, R204.1, R206.2, U201.2 (-)
unnamed: R205.2, U201.6 (-), U201.7
unnamed: C204.1, R212.1, U204.3 (+)
unnamed: R210.2, R211.1, R213.2, U204.2 (-)
unnamed: R212.2, U204.6 (-), U204.7
unnamed: C404.1, U401.2 (CAP+)
unnamed: C404.2, U401.4 (CAP-)
unnamed: C407.2, C408.1, FB401.1, U401.5 (VOUT)
unnamed: R702.1, U701.9 (CLK1)
unnamed: R701.1, U701.6 (CLK2)
unnamed: U701.2 (XA), Y701.3
unnamed: U701.3 (XB), Y701.1
unnamed: R801.2, R803.1, U802.3 (+)
unnamed: R802.1, R804.2, U802.2 (-)
unnamed: RV801.1, U802.1 (T)
unnamed: RV801.3, U802.8 (T)
VBUS: C502.1, F301.2, J301.19, J301.20, M501.2 (+), R503.2, R506.2

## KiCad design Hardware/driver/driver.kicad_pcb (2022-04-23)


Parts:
C101: 4.7µF; C_0805_2012Metric_Pad1.18x1.45mm_HandSolder; MPN CL21A475KAQNNNF
C102, C103: 10µF; CP_EIA-3216-18_Kemet-A_Pad1.58x1.35mm_HandSolder; MPN TAJA106K016RNJ
C104, C105, C106: 100nF; C_0805_2012Metric_Pad1.18x1.45mm_HandSolder
D101: Red; LED_0805_2012Metric_Pad1.15x1.40mm_HandSolder; MPN 150080SS75000
H101, H102, H103, H104: MountingHole; MountingHole_3.5mm
R101: MPN CR0805-JW-102ELF
TP101: -5V; TestPoint_Keystone_5000-5004_Miniature; MPN 5000
U101: ICL7660; SOIC-8_3.9x4.9mm_P1.27mm; MPN ICL7660CSA+T
U102: DS2482-100; SO-8_3.9x4.9mm_P1.27mm
U103: PI4IOE5V9536; MSOP-8_3x3mm_P0.65mm; MPN PI4IOE5V9536UEX

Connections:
+3V3: C105.1, C106.1, R101.1, U102.1 (VCC), U103.8 (VCC); also elsewhere on the board
+5V: C101.1, U101.8 (V+); also elsewhere on the board
-5V: C103.2, C104.1, TP101.1, U101.5 (VOUT); also elsewhere on the board
/1WIRE: U102.2 (IO); also elsewhere on the board
/I2C_SCL: U102.4 (SCL), U103.6 (SCL); also elsewhere on the board
/I2C_SDA: U102.5 (SDA), U103.7 (SDA); also elsewhere on the board
/SENSE_RST: U103.3 (P2); also elsewhere on the board
/SENSE_SET: U103.2 (P1); also elsewhere on the board
GND: C101.2, C103.1, C104.2, C105.2, C106.2, U101.3 (GND), U102.3 (GND), U102.7 (AD1), U102.8 (AD0), U103.4 (GND); also elsewhere on the board
unnamed: C102.1, U101.2 (CAP+)
unnamed: C102.2, U101.4 (CAP-)
unnamed: D101.1 (K), U103.5 (P3)
unnamed: D101.2 (A), R101.2

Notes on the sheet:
-5V Regulator
I²C address: 0b1000001
GPIO Expander
I²C address: 0b0011000

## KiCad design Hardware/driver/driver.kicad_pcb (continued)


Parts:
C301, C303, C304, C306, C307, C310, C312, C313, C315, C316, C319, C320: 100nF; C_0805_2012Metric_Pad1.18x1.45mm_HandSolder
C302, C311: 1nF; C_0805_2012Metric_Pad1.18x1.45mm_HandSolder
C305, C308, C314, C317: 10µF; CP_EIA-3216-18_Kemet-A_Pad1.58x1.35mm_HandSolder; MPN TAJA106K016RNJ
C309, C318: 470nF; C_0805_2012Metric_Pad1.18x1.45mm_HandSolder; MPN CL21B474KAFNNNE
C321: 1µF; C_0805_2012Metric_Pad1.18x1.45mm_HandSolder; MPN CL21B105KBFNNNG
D301: DSA120C150QB; TO-247-3_Vertical; MPN DSA120C150QB
D302: 5KP78A; D_P600_R-6_P20.00mm_Horizontal; MPN 5KP78A
FB301: FerriteBead_Small; L_0805_2012Metric_Pad1.05x1.20mm_HandSolder; MPN MFBM1V2012-800-R
HS301: 2x C40-058-AE; C40-058-AE-DUAL; MPN C40-058-AE
HS302: WV-T247-101E; Ohmite-WA-T247-101E-MFG; MPN WV-T247-101E
J302, J303: Würth 74651194R; WE-74651194; MPN 74651194R
Q301, Q302: IXTH80N075L2; TO-247-3_Vertical
R301, R309: .05R; TO-247-2_Vertical
R302, R310: MPN WR08X101-JTL
R303, R306, R311, R314: MPN CR0805-FX-4991ELF
R304, R305, R312, R313: MPN CR0805-JW-102ELF
R307, R315: 4M7; R_0805_2012Metric_Pad1.20x1.40mm_HandSolder; MPN 260-4.7M-RC
R308, R316: 2k2; R_0805_2012Metric_Pad1.20x1.40mm_HandSolder; MPN RMC1/10-222JTP
RV301, RV302: 10k; Potentiometer_Nidec_Copal_CT94EY; MPN CT-94EY103
U301: MCP3421A2T-ECH; SOT-23-6_Handsoldering
U302, U306: ADA4522-2; SOIC-8_3.9x4.9mm_P1.27mm; MPN ADA4522-2ARZ
U303, U307: DAC60501Z; VSSOP-10_3x3mm_P0.5mm; MPN DAC60501ZDGSR
U304, U308: LM431SC; SOT-23; MPN LM431SCCMFX
U305: MCP3421A3T-ECH; SOT-23-6_Handsoldering
U309, U310: DS18B20; TO-92_Inline

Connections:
+3V3: C301.1, C305.1, C307.1, C308.1, C310.1, C314.1, C316.1, C317.1, C319.1, C320.1, U301.5 (Vdd), U303.1 (VCC), U303.5 (SPI2C), U305.5 (Vdd), U307.1 (VCC), U307.5 (SPI2C), U309.3 (VDD), U310.3 (VDD); also elsewhere on the board
+12V: C303.1, C312.1, C321.1, U302.8 (V+), U306.8 (V+); also elsewhere on the board
-5V: R308.2, R316.2; also elsewhere on the board
/1WIRE: U309.2 (DQ), U310.2 (DQ); also elsewhere on the board
/I2C_SCL: U301.3 (SCL), U303.6 (SCL), U305.3 (SCL), U307.6 (SCL), U307.7 (~SYNC/A0); also elsewhere on the board
/I2C_SDA: U301.4 (SDA), U303.7 (~SYNC/A0), U303.8 (SDA), U305.4 (SDA), U307.8 (SDA); also elsewhere on the board
/Input Stage/DRIVE0: U302.5 (+), U303.2 (VOUT)
/Input Stage/DRIVE1: U306.5 (+), U307.2 (VOUT)
/Input Stage/ISense0: Q301.3 (S), R301.1, R303.2, R305.2
/Input Stage/ISense1: Q302.3 (S), R309.1, R311.1, R313.1
/Input Stage/VBUS_IN: D301.1 (K), D301.3 (K), D302.1 (A1), J302.1
/Input Stage/VREF0: C309.1, RV301.3, U303.10 (VREF)
/Input Stage/VREF1: C318.1, RV302.3, U307.10 (VREF)
GND: C301.2, C303.2, C304.1, C305.2, C306.2, C307.2, C308.2, C309.2, C310.2, C312.2, C313.2, C314.2, C315.2, C316.2, C317.2, C318.2, C319.2, C320.2, C321.2, FB301.2, U301.2 (Vss), U302.4 (V-), U303.4 (GND), U304.1 (K), U304.2 (REF), U305.2 (Vss), U306.4 (V-), U307.4 (GND), U308.1 (K), U308.2 (REF), U309.1 (GND), U310.1 (GND); also elsewhere on the board
GNDPWR: D302.2 (A2), FB301.1, J303.1, R301.2, R309.2, U301.6 (Vin-), U305.6 (Vin-); also elsewhere on the board
unnamed: C302.1, R302.2, U302.1
unnamed: C302.2, R304.1
unnamed: C304.2, R303.1, U301.1 (Vin+)
unnamed: C306.1, R306.1, U302.3 (+)
unnamed: C311.1, R310.2, U306.1
unnamed: C311.2, R312.1
unnamed: C313.1, R311.2, U305.1 (Vin+)
unnamed: C315.1, R314.1, U306.3 (+)
unnamed: Q301.1 (G), R302.1
unnamed: Q302.1 (G), R310.1
unnamed: R304.2, R305.1, R307.2, U302.2 (-)
unnamed: R306.2, U302.6 (-), U302.7
unnamed: R307.1, RV301.2
unnamed: R308.1, RV301.1, U304.3 (A)
unnamed: R312.2, R313.2, R315.2, U306.2 (-)
unnamed: R314.2, U306.6 (-), U306.7
unnamed: R315.1, RV302.2
unnamed: R316.1, RV302.1, U308.3 (A)
VBUS: D301.2 (A), Q301.2 (D), Q302.2 (D); also elsewhere on the board

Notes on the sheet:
Zero offset adjustment
I²C address: 0b1101010
I²C address: 0b1001011
I²C address: 0b1001010
Clips: CLA-T247-21E (TO-247) Insulator: Bergquist SP900S-0.009-00-104
Ringing prevention
Place one sensor per side of heatsink; as close to MOSFET as possible
Connector to front panel input jacks Würth REDCUBE THR series screw mount
~320Hz LPF
I²C address: 0b1101011
Mount heat sink to diode (insulator req'd!) Insulator: Bergquist SP900S-0.009-00-104


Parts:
C201, C213: 10µF; CP_EIA-3216-18_Kemet-A_Pad1.58x1.35mm_HandSolder; MPN TAJA106K016RNJ
C202, C204, C208, C210, C212, C214: 100nF; C_0805_2012Metric_Pad1.18x1.45mm_HandSolder
C203, C206, C207, C209, C216, C217, C220, C221: 4.7µF; C_0805_2012Metric_Pad1.18x1.45mm_HandSolder; MPN CL21A475KAQNNNF
C205: 10µF; C_0805_2012Metric_Pad1.18x1.45mm_HandSolder; MPN TMK212BBJ106MG-T
C211: 10µF; CP_EIA-3528-21_Kemet-B_Pad1.50x2.35mm_HandSolder; MPN TAJB106K025TNJ
C215: 10µF; CP_Radial_D5.0mm_P2.00mm; MPN 860010472002
C218: 47µF; CP_Radial_D6.3mm_P2.50mm; MPN A750EK476M1EAAE040
D201, D202, D204, D205, D206: Green; LED_0805_2012Metric_Pad1.15x1.40mm_HandSolder; MPN 150080VS75000
F201: 350mA; Fuse_1210_3225Metric_Pad1.42x2.65mm_HandSolder; MPN 0ZCH0035FF2G
J201: Conn_02x10_Odd_Even; IDC-Header_2x10_P2.54mm_Vertical; MPN T821120A1S100CEU
JP201: Cfg WP; PinHeader_1x03_P2.54mm_Vertical
L201: 6.8µH; L_Taiyo-Yuden_NR-24xx_HandSoldering; MPN NRH2410T6R8MN
M201: Fan_4pin; Molex-47053-1000-MFG; MPN 47053-1000
PS201: PCN2-S12-S15-S; CONV_PCN2-S12-S15-S
Q201: MMBT3904; SOT-323_SC-70_Handsoldering; MPN MMBT3904,215
Q202: PN2222A; TO-92_Inline; MPN PN2222ATA
R201, R202, R214, R215: MPN RMC1/10-222JTP
R203, R205: 2k2; R_0805_2012Metric_Pad1.20x1.40mm_HandSolder; MPN RMC1/10-222JTP
R204: 4k99; R_0805_2012Metric_Pad1.20x1.40mm_HandSolder; MPN CR0805-FX-4991ELF
R206: 1k; R_0805_2012Metric_Pad1.20x1.40mm_HandSolder; MPN CR0805-JW-102ELF
R208: MPN CR0805-JW-102ELF
R210, R211, R213: MPN RMC1/10-103JTP
R212, R217: 4k7; R_0805_2012Metric_Pad1.20x1.40mm_HandSolder
R216: 27k4; R_0805_2012Metric_Pad1.20x1.40mm_HandSolder
R218: 7k5; R_0805_2012Metric_Pad1.20x1.40mm_HandSolder; MPN WR08X752 JTL
U201: AT24CS32-SSHM; SOIC-8_3.9x4.9mm_P1.27mm
U202: MIC5366-3.3YC5; SOT-353_SC-70-5; MPN MIC5366-3.3YC5-TR
U203: ADUM1250; SOIC-8_3.9x4.9mm_P1.27mm
U204: MCP1804x-C002xMB; SOT-89-3; MPN MCP1804T-C002I/MB
U205: FODM217B; SOP-4_4.4x2.6mm_P1.27mm; MPN FODM217B
U206: EMC2101-R; MSOP-8_3x3mm_P0.65mm; MPN EMC2101-R-ACZL-TR
U207: MCP1703AT-5002E/DB; SOT-223-3_TabPin2; MPN MCP1703AT-5002E/DB

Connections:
+3V3: C201.1, C202.1, C203.1, C204.1, JP201.3 (B), R201.2, R202.2, R206.1, U201.8 (VCC), U202.5 (VOUT), U203.8 (VDD2); also elsewhere on the board
+3V3A: C208.1, C210.1, C213.1, C214.1, J201.15, R210.1, R211.1, R214.2, R215.2, U203.1 (VDD1), U206.1 (VCC)
+5V: C206.1, C216.1, R205.1, U202.1 (VIN), U202.3 (EN), U207.3 (VO); also elsewhere on the board
+5VA: J201.13
+12V: C220.1, R204.1, U204.1 (OUT); also elsewhere on the board
+12VA: C211.1, C212.1, C215.1, F201.2, J201.17, J201.19, M201.2 (+), R212.2, R217.2; also elsewhere on the board
+15V: C205.1, C217.1, C218.1, C221.1, PS201.6 (+Vout), R218.1, U204.3 (IN), U207.1 (VI); also elsewhere on the board
-5V: R203.1; also elsewhere on the board
/External Interface/EXT_SCL: J201.1, U203.3 (SCL1), U206.8 (SMCLK)
/External Interface/EXT_SDA: J201.3, U203.2 (SDA1), U206.7 (SMDATA)
/External Interface/FAN_PWM: Q201.1 (B), R210.2, U206.4 (FAN)
/External Interface/FAN_TACH: R211.2, R213.2, R216.2, U206.6 (TACH)
/External Interface/TEMP_DN: Q202.1 (E), U206.3 (DN)
/External Interface/TEMP_DP: Q202.2 (B), Q202.3 (C), U206.2 (DP)
/External Interface/~EXT_IRQ: J201.5, R214.1
/External Interface/~EXT_RESET: J201.9
/External Interface/~EXT_TRIG: J201.7, R215.1, U205.4
/I2C_SCL: R201.1, U201.6 (SCL), U203.6 (SCL2); also elsewhere on the board
/I2C_SDA: R202.1, U201.5 (SDA), U203.7 (SDA2); also elsewhere on the board
/TRIGGER: R208.2; also elsewhere on the board
GND: C201.2, C202.2, C203.2, C204.2, C205.2, C206.2, C216.2, C217.2, C218.2, C220.2, C221.2, D201.1 (K), D202.1 (K), D204.1 (K), D205.2 (A), D206.1 (K), JP201.1 (A), PS201.4 (-Vout), U201.1 (A0), U201.2 (A1), U201.3 (A2), U201.4 (GND), U202.2 (GND), U203.5 (GND2), U204.2 (GND), U205.2, U207.2 (GND); also elsewhere on the board
GNDA: C207.2, C208.2, C209.2, C210.2, C211.2, C212.2, C213.2, C214.2, C215.2, J201.2, J201.4, J201.6, J201.8, J201.10, J201.12, J201.14, J201.16, J201.18, J201.20, M201.1 (-), PS201.2 (-Vin), Q201.2 (E), R213.1, U203.4 (GND1), U205.3, U206.5 (GND); also elsewhere on the board
unnamed: C207.1, L201.1, PS201.1 (+Vin)
unnamed: C209.1, F201.1, L201.2
unnamed: D201.2 (A), R205.2
unnamed: D202.2 (A), R206.2
unnamed: D204.2 (A), R218.2
unnamed: D205.1 (K), R203.2
unnamed: D206.2 (A), R204.2
unnamed: JP201.2 (C), U201.7 (WP)
unnamed: M201.3 (Tacho), R216.1, R217.1
unnamed: M201.4 (PWM), Q201.3 (C), R212.1
unnamed: R208.1, U205.1

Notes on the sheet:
I²C address: 0b1010000/0b1011000
C205 is ceramic
Host loads regs, fan at 0%
Place Q202 on/near heatsink, connected via twisted pair wire Used for hardware fan control
I²C address: 0b1001100


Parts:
C501: 100nF; C_0805_2012Metric_Pad1.18x1.45mm_HandSolder
C502: MPN CL21B105KBFNNNG
D501: 1N4148W; D_SOD-123; MPN 1N4148W-AU_R1_000A1
J501: Conn_Coaxial; CONN_1-1337543-0; MPN 1-1634624-0
R501: MPN RMC1/10-103JTP
R502: 47k; R_0805_2012Metric_Pad1.20x1.40mm_HandSolder; MPN RMC1/10-473JTP
R503: 100R; R_0805_2012Metric_Pad1.20x1.40mm_HandSolder; MPN WR08X101-JTL
RV501: 500k; Potentiometer_Nidec_Copal_CT94EW; MPN CT-94EW504
TP501: Trigger; TestPoint_Keystone_5000-5004_Miniature; MPN 5004
U501: 74LVC1G17; SOT-23-5_HandSoldering; MPN SN74LVC1G17DBVRG4
U502: FODM217B; SOP-4_4.4x2.6mm_P1.27mm; MPN FODM217B

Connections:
+3V3: C501.1, U501.5 (VCC), U502.4; also elsewhere on the board
/TRIGGER: R501.2, U501.4; also elsewhere on the board
GND: C501.2, R501.1, R502.1, RV501.1, RV501.2, U501.3 (GND); also elsewhere on the board
unnamed: C502.1, RV501.3, TP501.1, U501.2
unnamed: C502.2, R502.2, U502.3
unnamed: D501.1 (K), R503.1, U502.1
unnamed: D501.2 (A), J501.2 (Ext), U502.2
unnamed: J501.1 (In), R503.2


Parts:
C401: MPN CL21B105KBFNNNG
C402, C403: 330µF; CP_Radial_D8.0mm_P3.50mm; MPN A750KS337M1EAAE018
D401: SM6T22A; D_SMB
D402: Green; LED_0805_2012Metric_Pad1.15x1.40mm_HandSolder; MPN 150080VS75000
J401: TBP02R2W-381-03BE; CUI_TBP02R2W-381-03BE
J402: Conn_01x02_Male; JST_VH_B2P-VH-B_1x02_P3.96mm_Vertical
L401: Choke; TDK-ACM1513-0-0-MFG; MPN ACM1513-551-2PL-TLHF
PS401: PSK-S20C-12; CONV_PSK-S20C-12; PARTREV 1.0
R401: 4k7; R_0805_2012Metric_Pad1.20x1.40mm_HandSolder
RV401: 270V; RV_Disc_D7mm_W4.2mm_P5mm; MPN 271KD07-TR
TP401: +5V; TestPoint_Keystone_5000-5004_Miniature; MPN 5000
TP402: +3V3; TestPoint_Keystone_5000-5004_Miniature; MPN 5000
TP403: GND; TestPoint_Keystone_5000-5004_Miniature; MPN 5001
TP404: +15V; TestPoint_Keystone_5000-5004_Miniature; MPN 5000
TP405: +12V; TestPoint_Keystone_5000-5004_Miniature; MPN 5000

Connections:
+3V3: TP402.1; also elsewhere on the board
+5V: TP401.1; also elsewhere on the board
+12V: TP405.1; also elsewhere on the board
+12VA: C401.1, C402.1, C403.1, D401.1 (A1), L401.4, R401.1; also elsewhere on the board
+15V: TP404.1; also elsewhere on the board
/Mains Supply (Optional)/MAINS_G: J401.2
/Mains Supply (Optional)/MAINS_L: J401.1, PS401.2 (AC(L)), RV401.1
/Mains Supply (Optional)/MAINS_N: J401.3, PS401.1 (AC(N)), RV401.2
GND: TP403.1; also elsewhere on the board
GNDA: C401.2, C402.2, C403.2, D401.2 (A2), D402.1 (K), L401.3; also elsewhere on the board
unnamed: D402.2 (A), R401.2
unnamed: J402.1, L401.1, PS401.4 (+VO)
unnamed: J402.2, L401.2, PS401.3 (-VO)

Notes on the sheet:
Mate with TBP02P1W-381-03BE


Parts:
C601, C603, C604, C605: 100nF; C_0805_2012Metric_Pad1.18x1.45mm_HandSolder
C602, C606: 10µF; CP_EIA-3216-18_Kemet-A_Pad1.58x1.35mm_HandSolder; MPN TAJA106K016RNJ
C607: 10µF; CP_Radial_D5.0mm_P2.00mm; MPN 860010472002
D601: 2V4; D_MiniMELF_Handsoldering; MPN BZV55-C2V4,135
D602, D603: SM4007; D_SMA_Handsoldering; MPN FM4007W-W
J601: Screw_Terminal_01x02; CUI_TBL002A-350-02GR-2OR; MPN TBL002A-350-02GR-2OR
K601: EC2-5TNU; Relay_DPDT_Kemet_EC2_DoubleCoil; MPN EC2-5TNU
Q601, Q602: MMBT3904; SOT-323_SC-70_Handsoldering; MPN MMBT3904,215
R601, R602: 1M .1%; R_0805_2012Metric_Pad1.20x1.40mm_HandSolder; MPN RN73C2A1M0BTDF
R603, R604: 20k .1%; R_0805_2012Metric_Pad1.20x1.40mm_HandSolder; MPN ERA-6ARB203V
R605: MPN CR0805-FX-4991ELF
R606, R607: 10k; R_0805_2012Metric_Pad1.20x1.40mm_HandSolder; MPN RMC1/10-103JTP
RV601: 20k; Potentiometer_Nidec_Copal_CT94EY; MPN CT-94EY203
TP601: VSense+; TestPoint_Keystone_5000-5004_Miniature; MPN 5004
TP602: VSense-; TestPoint_Keystone_5000-5004_Miniature; MPN 5001
U601: MCP3421A1T-ECH; SOT-23-6_Handsoldering
U602: OPA277; SOIC-8_3.9x4.9mm_P1.27mm

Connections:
+3V3: C601.1, C602.1, U601.5 (Vdd); also elsewhere on the board
+5V: C604.1, C606.1, C607.1, D602.1 (K), D603.1 (K), K601.1, K601.6, RV601.2, U602.7 (V+); also elsewhere on the board
-5V: C605.1, U602.4 (V-); also elsewhere on the board
/I2C_SCL: U601.3 (SCL); also elsewhere on the board
/I2C_SDA: U601.4 (SDA); also elsewhere on the board
/Input Stage/Voltage Sense/SEL_RESET: D603.2 (A), K601.7, Q601.3 (C)
/Input Stage/Voltage Sense/SEL_SET: D602.2 (A), K601.12, Q602.3 (C)
/Input Stage/Voltage Sense/SENSE+: J601.1, K601.8
/Input Stage/Voltage Sense/SENSE-: J601.2, K601.5
/Input Stage/Voltage Sense/VIN+: K601.9, R602.1
/Input Stage/Voltage Sense/VIN-: K601.4, R601.2
/Input Stage/Voltage Sense/VSENSE: D601.1 (K), R603.1, R605.2, U602.6
/SENSE_RST: Q601.1 (B), R607.2; also elsewhere on the board
/SENSE_SET: Q602.1 (B), R606.2; also elsewhere on the board
GND: C601.2, C602.2, C603.2, C604.2, C605.2, C606.2, C607.2, D601.2 (A), Q601.2 (E), Q602.2 (E), R604.2, R606.1, R607.1, TP602.1, U601.2 (Vss), U601.6 (Vin-); also elsewhere on the board
GNDPWR: K601.3; also elsewhere on the board
unnamed: C603.1, R605.1, TP601.1, U601.1 (Vin+)
unnamed: R601.1, R603.2, U602.2 (-)
unnamed: R602.2, R604.1, U602.3 (+)
unnamed: RV601.1, U602.1 (T)
unnamed: RV601.3, U602.8 (T)
VBUS: K601.10; also elsewhere on the board

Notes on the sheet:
External VSense input
Voltage ADC
Differential Amp (50:1 gain)
I²C address: 0b1101001
Relay Driver
VSense Selection



Board: 4 copper layers, 128.1 x 184.5 mm, 189 parts (8 on the bottom side), 87 nets.

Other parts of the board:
kibuzzard-6248DD82: G***; kibuzzard-6248DD82
kibuzzard-6248DDB7: G***; kibuzzard-6248DDB7
kibuzzard-6248DE02: G***; kibuzzard-6248DE02
kibuzzard-6248DE32: G***; kibuzzard-6248DE32
kibuzzard-6248DECB: G***; kibuzzard-6248DECB
kibuzzard-6250772E: G***; kibuzzard-6250772E

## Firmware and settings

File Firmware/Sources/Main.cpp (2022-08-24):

#include "Log/Logger.h"
#include "Rtos/Start.h"

#include "BuildInfo.h"

#include "stm32mp1xx_hal_rcc.h"

#include "Drivers/Random.h"
#include "Hw/StatusLed.h"
#include "Rpc/Rpc.h"
#include "Rtos/Rtos.h"
#include "Supervisor/Supervisor.h"

#include "App/Rpmsg/Task.h"

/**
 * @brief Early hardware init
 *
 * This un-gates various clocks and enables some basic peripherals (RCC, GPIO) that we will need
 * throughout the life of the software.
 */
static void EarlyHwInit() {
    // enable hardware semaphores
    __HAL_RCC_HSEM_CLK_ENABLE();

    // set up status indicator
    Hw::StatusLed::Init();
    Hw::StatusLed::Set(Hw::StatusLed::Color::Yellow);

    // initialize a few peripherals
    // Drivers::Random::Init();
}

/**
 * @brief Application entry point
 *
 * We'll jump here after the chip is mostly set up; that is, the RAM regions are established. We
 * should then perform low-level hardware initialization (clocks, peripherals, IOs) and set up the
 * tasks and other OS resources.
 *
 * Lastly, the RTOS scheduler is launched to actually begin execution.
 */
extern "C" int main() {
    /*
     * Perform early initialization (status indicators, to show sign of life; and clocks for some
     * internal peripherals) then log a message indicating that we're alive before proceeding with
     * the actual initialization.
     */
    EarlyHwInit();

    Logger::Warning("Programmable load rtfw (%s/%s-%s) built on %s by %s@%s",
            gBuildInfo.gitBranch, gBuildInfo.gitHash, gBuildInfo.buildType,
            gBuildInfo.buildDate,
            gBuildInfo.buildUser, gBuildInfo.buildHost);
    Logger::Notice("MPU clock: %u Hz", SystemCoreClock);

    /*
     * Initialize host RPC interface
     *
     * This prepares the tasks used to communicate with the host via the Linux rpmsg interface,
     * and a virtio device managed via OpenAMP.
     *
     * Actual communication won't take place until the FreeRTOS scheduler is started, as a
     * background task handles all the message processing.
     */
    Rpc::Init();

    /*
     * Create the supervisory tasks, which are responsible for thermal control of the system and
     * ensuring all tasks that should be running are, and aren't hung.
     *
     * These in turn feed into the hw watchdog, which is activated from this point on.
     */
    Supervisor::Init();

    /*
     * Set up the actual application specific tasks
     *
     * This consists of the load interface (this runs the driver communicating with the
     * peripherals on the analog board over SPI and I²C) task, the control loop task, and the
     * associated remote message io handlers.
     */
    App::Control::Start();
    App::Rpmsg::Start();

    /*
     * Last, transfer control to the FreeRTOS scheduler. This will begin executing the app main
     * task, which in turn performs all initialization with full scheduling services available.
     *
     * We do it this way so that our initialization can rely on stuff like timers working.
     */
    Rtos::StartScheduler();
}

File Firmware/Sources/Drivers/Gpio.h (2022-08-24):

#ifndef DRIVERS_GPIO_H
#define DRIVERS_GPIO_H

#include <stdint.h>

#include <etl/utility.h>

namespace Drivers {
/**
 * @brief PORT / GPIO driver
 *
 * Provides methods to configure IO pins, as well as interface with the digital input/output pins.
 */
class Gpio {
    public:
        /**
         * @brief GPIO port
         *
         * The device has multiple "banks" of IO ports, each identified by a single letter. Inside
         * each port are up to 16 pins, numbered 0-31.
         */
        enum class Port: uint8_t {
            PortA                       = 1,
            PortB                       = 2,
            PortC                       = 3,
            PortD                       = 4,
            PortE                       = 5,
            PortF                       = 6,
            PortG                       = 7,
            PortH                       = 8,
            PortI                       = 9,
            // Port Z is accessible only from the A7 core
        };

        /**
         * @brief IO pin mode
         *
         * Defines the direction and/or mode of the IO pin.
         */
        enum class Mode: uint8_t {
            /// Pin is disabled (unused)
            Off,
            /// Configure pin as a digital input
            DigitalIn,
            /// Configure pin as a digital output
            DigitalOut,
            /// Use the pin for analog functions
            Analog,
            /**
             * @brief Peripheral multiplexer mode (alternate function)
             *
             * The direction and output drive is controlled by the peripheral associated by the
             * port mux function specified in the `function` field of PinMode.
             */
            Peripheral,
        };

        /// Pull up/down resistor configuration
        enum class Pull: uint8_t {
            /// No pull up/down resistors
            None,
            /// Enable a pull-up resistor (towards VCC)
            Up,
            /// Enable a pull-down resistor (towards GND)
            Down,
        };

        /**
         * @brief Pin location
         *
         * A combination of GPIO port and pin that can be used to uniquely identify a GPIO pin.
         */
        using Pin = etl::pair<Port, uint8_t>;

        /**
         * @brief Pin mode definition
         *
         * Encapsulates the configuration for a particular pin. This includes whether the pin is an
         * input or output, pull up/down resistors, or whether the pin is in use for an alternate
         * function.
         */
        struct PinConfig {
            /**
             * @brief Pin mode
             *
             * Specifies the way this pin is used, including the peripherals that may have access
             * to it or how it is used.
             */
            Mode mode{Mode::Off};

            /**
             * @brief Pull resistor configuration
             *
             * When the pin is disabled, or configured as digital IO, configurable pull-up or pull-
             * down resistors may be enabled.
             */
            Pull pull{Pull::None};

            /**
             * @brief Whether the output operates in open drain mode
             *
             * When set, the output operates in open drain mode: that is, the output will only be
             * pulled low. This bit is ignored if the pin is not configured as an output.
             */
            uint8_t isOpenDrain: 1{0};

            /**
             * @brief Peripheral function
             *
             * @remark Only relevant when the pin mode is Mode::Peripheral.
             */
            uint8_t function: 4{0};

            /**
             * @brief Pin IO speed
             *
             * Sets the expected IO output speed, from low (0) to highest (3). This affects the
             * drive strength and other properties.
             */
            uint8_t speed: 2{1};

            /**
             * @brief Initial output state
             *
             * When configured as a digital output, this bit is written to the output latch before
             * the output driver is enabled, so the pin starts at a predictable level.
             */
            uint8_t initialOutput: 1{0};
        };

    public:
        Gpio() = delete;

        static void ConfigurePin(const Pin pin, const PinConfig &config);

        static void SetOutputState(const Pin pin, const bool state);

        static bool GetInputState(const Pin pin);

    private:
        static void EnablePortClock(const Port);

        static void AcquireLock();
        static void UnlockGpio();

        /// ID of the semaphore slot used for GPIOs; fixed by linux code
        constexpr static const size_t kSemaphoreId{0};
        /// Maximum number of times to try acquiring the lock before giving up
        constexpr static const size_t kLockRetries{5000};
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

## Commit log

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2022-03-05 Minor tweaks to layout/schematic
    - Use a DC/DC to generate 5V, then generate 3V3 via an LDO from that:
    this should help filter out more of the switching noise out of the
    supplies.
    Also, this included adding a 330Ω load resistor so that the DC/DC gets
    the minimum load it expects; it burns ~15mA at 5V.
    - Changes to pass DRC
    [acdc.kicad_sch, driver.kicad_pcb, driver.kicad_sch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]
2022-03-06 Fixed some part numbers in schematic
    - Also updated some of the annotations, they were out-of-date with
    respect to what the current status was
    [driver.kicad_sch, input.kicad_sch, interface.kicad_sch]
2022-03-06 Minor tweaks to driver board layout
    - Moved around some signals around the heat sink and moved the input
    jack downwards to reduce interference with fan
    [driver.kicad_pcb]
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2022-03-06 Added basic rear IO connector
    - Placed the connector for the rear IO board, which will carry USB, I2C,
    Ethernet and power. Currently, USB and I2C have been hooked up.
    - Added an I2C switch. This will allow sharing the secondary I2C bus
    between the front panel and rear IO, without needing to worry about
    address conflicts or other such issues.
    Removed the on-board I2C EEPROM; we have a NOR flash instead.
    [controller.kicad_pcb, controller.kicad_sch, cpu.kicad_sch]
2022-03-07 Added Ethernet PHY
    - Placed the Ethernet PHY on the controller board, and routed its lines
    to the rear panel connector. The MAC address will be stored in the NOR
    flash, and will need to be programmed in. (This avoids the complexity
    of needing a larger I2C switch to give us another bus for an I2C
    EEPROM; though we could ostensibly put one on the rear IO board.)
    [controller.kicad_pcb, controller.kicad_sch, cpu.kicad_sch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]
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2022-03-09 Added beeper to control board
    - Added a beeper (magnetic transducer, including an amplifier to go with
    it) to the controller board so we can make loud annoying beeping
    noises as desired
    - A few minor tweaks to the layout of the control board
    [controller.kicad_pcb, controller.kicad_sch, cpu.kicad_sch]
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2022-03-12 Start work on remote VSense; driver board tweaks
    - Use the DAC reference as the positive end of the null adjustment
    trimmers, rather than the +3V3 supply; this should make the adjustment
    actually useful and persistent rather than relying on the relationship
    between the 3V3 rail and the DAC's internal reference.
    - Moved the 1Wire controller slightly to allow relocating the zero
    offset trimmer for the first channel
    - Start work on remote VSense
    This works by selecting between either voltage sensing at the source
    terminals, or an external sense input connected to another set of
    terminals. These are switched by a latching relay (as to provide
    satisfying clicky noises) and then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
    [acdc.kicad_sch, driver.kicad_pcb, driver.kicad_sch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]
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2022-03-13 Initial commit of firmware
    - Created a basic firmware skeleton for the processor board. It doesn't
    do anything other than print a message via SWO and then blink the
    status LED on the board (in theory, lol.)
    [Main.cpp]
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2022-03-14 Driver input protection; heatsink footprint tweaks
    - Updated the footprint for the heatsink on the driver board to include
    a 3D model. Also fixed it… the distances were kind of out of whack and
    it would never have really fit
    - Added a reverse polarity protection diode to the input; it gets its
    own cute little heatsink
    - Minor movement to better accomodate a fan. A 20mm fan will likely
    interfere with the input connector (it might be worth switching to a
    different kind, or just soldering the connections altogether: spade
    terminals seem like a good choice for high current) and be very tight
    against the input diode's heatsink. We'll try with a 10mm fan and see
    if that's enoug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
    [controller.kicad_pcb, controller.kicad_sch, driver.kicad_pcb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]
2022-03-14 Replaced load input connector
    - Switched out the screw terminal for a pair of PCB mount studs, which
    then accept the wires from the front panel (with crimped hook or loop
    ferrules) and an associated nut.
    This gives way more clearance for a fan so hopefully a big high
    velocity one can fit.
    - Moved input protection diodes up some more
    [driver.kicad_pcb, driver.kicad_sch, input.kicad_sch]
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2022-03-20 Start work on timer/counter driver
    - Begin work on a timer/counter driver. This is primarily intended to
    generate PWM waveforms, but can also be adapted to generate periodic
    interrupts with a little bit of work.
    It will be used to drive the magnetic transducer on the main board for
    those fun annoying beeping sounds.
    - Expose peripheral clock configuration from vendor code as a header
    - Fixed SPI and GPIO enable to set just that bit, as it takes priority
    [Gpio.cpp, Gpio.h, Spi.cpp]
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2022-03-21 WIP I2C driver
    - Created a basic interrupt-driven I2C driver; currently, it works only
    in master mode, transfering 8 bits at a time. It actually might not
    work at all because the hardware doesn't exist yet lol
    - Added SERCOM helper to get the vector numbers for an interrupt
    [I2C.cpp, Spi.cpp]
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2022-03-21 Reworked /I2C_IRQ line
    - Moved the /I2C_IRQ signal to PA10 so that it no longer conflicts with
    the external interrupt (EIC) input line for the encoder at PB07.
    - Remove the superfluous UART header, as we're not actually going to use
    the UART for anything. This will all take place over USB CDC instead,
    and use SWD for early boot output.
    [controller.kicad_pcb, controller.kicad_sch, cpu.kicad_sch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]
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2022-03-29 Tweaks to work on real hardware
    - Fixed up GPIO init for blinky in main loop (for testing) to use our
    GPIO drivers, rather than the vendor provided stuff which just hangs
    (lol) for some reason
    - Progress on making trace SWO work; it seems very janky at the moment
    so idk why that is
    - Make some tweaks to ensure that this code can build with unmodified
    dependencies
    [Main.cpp]
2022-03-29 More clocking, SWO tweaks
    - Increased startup time for crystal oscillators and disabled clock
    failure detection; this resulted in false triggerings and the clocks
    for the system would get all janky
    - Fixed prescaler calculation for SWO to generate roughly ~30MHz trace
    clock
    This corresponds to the JLink GDB server command to configure the SWO
    with default values: "monitor SWO EnableTarget 120000000 0 1 0"
2022-03-30 More SWO tweaks; add clock management driver
    - Created a driver to abstract away all the nonsense clock configuration
    tasks, which is a sort of "umbrella" driver for MCLK and GCLK blocks
    in the chip.
    - Tweaks to FreeRTOS config for the 3 priority bits we have on the chip
    - Do not re-initialize trace SWO hardware; expect that the debugger has
    done this. This ensures the baud rate is correct-ish.
    - Added some debug logging to various parts as we try to start bringing
    up the RTOS stuff; it crashes with a hard fault now at the start :(
    [Main.cpp]
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2022-03-31 Minor fixes for building
    - Fix the baud rate calculation for SWO, for good this time, lmfao? idk
    it's reasonably stable and kind of a pain in the dick
    - Added hard fault handler
    - Modified main/isr stack size to be larger
    - Better handling of FreeRTOS asserts
    [Main.cpp]
2022-03-31 I2C driver tweaks
    - Fixed a few minor bugs in the I2C driver; it seems to work now for the
    most part for the basic transactions used by the bus mux and the fan
    controller.
    - Implemented reset handling for control driver board; it does a general
    call reset, as well as pulsing the reset line.
    - Ensure SERCOM base enables the APB clocks as needed
    [I2C.cpp]
2022-03-31 Enable clocks for timer/counter
    - Updated the timer/counter driver to enable the peripheral clock (GCLK
    channel) and the associated APB clock for the timer peripheral when
    it's being initialized.
    - Changed the duty cycle setter for timer/counters to take a float
    between 0 and 1, and fixed its calculation.
2022-03-31 USB config tweaks
    - Enable the required clocks for the USB peripheral as needed
    There's also (possibly? lol) a bug in the tinyusb stack for the SAMD5x
    devices; it waits for the SWRESET SYNCBUSY bit to go from 0 -> 1,
    which may never happen if the core is fast enough, causing the system
    to lock up. Need to investigate if this is intended behavior or a bug,
    then possibly submit a PR.
    [Main.cpp]
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2022-04-04 Read control board IDPROM
    - Control task reads the IDPROM on the front IO board on startup to
    identify the type of IO panel connected and to instantiate the correct
    driver
    - Extended inventory ROM handler with new atom types, and made some
    minor modifications to the API
    - Added base32 encode/decode helper
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2022-04-05 I2C driver, inventory fixes
    - Fixed an issue that caused I2C reads longer than one byte to fail due
    to a spurious interrupt.
    - Added the ability to have two back-to-back I2C transactions, which do
    not have a repeated start or stop condition between them. This is
    useful for putting large requests in several different buffers.
    - Fixed some endianness issues with inventory ROM parser
    - Panic function prints out scheduler state (including all tasks and
    their state) if scheduler has been started
    [AT24CS32.cpp, I2C.cpp]
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2022-04-07 Minor fixes to SPI driver
    - Fixed the SPI driver to not use 32-bit data mode (for now) since we
    need to refactor the IO loop for that
    - Tweaks to display driver to make it actually work
    - Minor tweaks to other code for more logging
    [Spi.cpp]
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2022-04-10 Implement 32-bit SPI mode
    - SPI driver (in polled mode) now writes 32 bits at a time to the data
    register, which allows us to keep up with high speed transfers a bit
    better. This does as much as possible of the transfer as 32 bit
    blocks, then transfers the last 3 or fewer bytes in one final
    transaction.
    Due to this, there is a short delay (up to 1µS) between the last
    full block, and the partial block
    This is mostly in preparation for supporting DMA, where the better bus
    utilization is key to performance.
    - Fixed missing gain calculation in dumb load driver
    [Spi.cpp]
2022-04-10 Front IO driver fixes
    - Initialize the IO expander on the HMI driver, and configure it to
    generate interrupts from the switches/buttons. These are read in the
    interrupt handler, and we can then tell which buttons were pressed or
    released.
    - Implemented HMI driver routine to set indicator state
    - Fixed the XRA1203 driver (re: handling 16-bit writes) so that
    initializing it actually works
2022-04-10 Basic encoder state machine, I2C fixes
    - Wrote a basic state machine to decode the Grey coded rotary encoder
    for the front panel. It accumulates rotations in a delta counter, and
    notifies the UI task whenever this counter is updated; the task then
    consumes that counter for the UI.
    - Fixed (maybe? lol) a race condition that would cause I2C transactions
    to hang when there were a lot of interrupts (from button mashing the
    front panel, for example) on the bus, and we had to sample the bus
    switch but something else in another task was trying to read the IO
    expander on the front panel.
    The tentative fix for this is to perform the first transaction setup
    inside a critical sectio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
    [I2C.cpp]
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2022-04-10 More rev 2 driver board work
    - Updated power supply section with linear regulators for the +12V and
    +5V rails
    - Replaced op amps for driving the MOSFETs with different ones, and
    updated them so that they actually run off the 12V rail instead of the
    3V3 rail.
    [acdc.kicad_sch, driver.kicad_pcb, driver.kicad_sch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]
2022-04-10 Rev 2 for front panel
    - Adds debouncing for all switches on the board itself, and fixes the
    incorrect RGB LED footprint.
    - Fix Omron B3W-9XXX switch footprints (they had soldermask over copper)
    [front.kicad_pcb, front.kicad_sch]
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2022-04-10 More tweaks to rev 2 front panel
    - Added on-board pull ups for encoder lines, to reduce noise carried on
    the lines
    - Cleaned up a few traces
    - Actually fixed the footprint of the RGB LED so that not only does the
    common terminal match up, as do all three of the color terminals also
    :D
    [front.kicad_pcb, front.kicad_sch]
2022-04-10 More work on rev2 driver board
    - Tweaked the board layout for the load driver some more, primarily
    relating to power and friends
    - Fixed footprint of fan connector on driver board (to properly have the
    mechanical mounting hole)
    - Manufacturability/solderability tweaks for a few other footprints
    [acdc.kicad_sch, driver.kicad_pcb, driver.kicad_sch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]
2022-04-10 Fixed I2C bus reversal on driver
    - Fixed an issue where SCL and SDA for the I2C bus were swapped beyond
    the interface sheet, meaning only the EEPROM is accessible over the
    bus. (This can probably be bodged relatively simply on a rev1 board on
    the bottom where the I2C bus runs)
    - Manufacturability tweaks for TDK choke
    [driver.kicad_pcb, driver.kicad_sch, interface.kicad_sch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]
2022-04-10 Rev2 fixes for controller board
    - Split power button into two separate IO lines
    - Fixed missing pull-ups on IO I2C bus, and routed interrupt line
    correctly
    - Cutouts for bosses in case on board
    [controller.kicad_pcb, controller.kicad_sch, cpu.kicad_sch]
2022-04-10 More controller board stuff
    - Fixed the fan connector (to accomodate the physical/mechanical hole
    for the connector)
    - Tweaked some more footprints to make them easier to solder
    [controller.kicad_pcb, controller.kicad_sch, cpu.kicad_sch]
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2022-04-10 Final bits of tweaks for rev2 analog board
    - Fixed footprint of MMBT3904 transistors on driver and controller
    boards (it is SOT-323, not SC-70)
    - A few more minor modifications to the layout of the analog driver
    board for rev2
    [controller.kicad_pcb, controller.kicad_sch, cpu.kicad_sch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]
2022-04-10 Fixed a few more footprints
    - Made heatsink and connector mechanical/mounting pads NPTH instead of
    normal pads, so they're not tempted to be connected to regular signals
    on the board and get more keepout space
    [driver.kicad_pcb, driver.kicad_sch, input.kicad_sch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]
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2022-04-11 Added hw info and hash helpers; version screen
    - Added a hardware info helper: this retrieves the serial number from
    the on chip registers, hashes it, and formats it for display with
    base32, and also gets the hw revision (or it will at some point lmfao
    it's hardcoded now)
    - Added hash helpers, currently just MurmurHash3
    - Minor fixes to font drawing API
    - Created a separate file for the version splash screen, which is also
    where we can declare a bunch of other screens for use in the pinball
    task
    - Added a small 10 point font, for subtitles/explanatory text. It's used
    for the software/hardware version text on the version splash
    [Main.cpp]
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2022-04-12 Fixes for menu handling
    - Fixed animations for dismissing the views, and also implemented
    popping screens off the navigation stack. (It ensures there will
    always be at least one screen remaining when done.)
    The handling is a little janky but whatever
    - Implement the default menu action, which dismisses the currently
    topmost menu on the nav stack.
    - Fixed menu/select button confusion in HMI driver
2022-04-12 Refactor for GUI screen definitions
    - Definitions are now static structs, meaning screens can be defined in
    ROM to save on .data section overhead at runtime. This means a little
    bit more overhead when drawing but we can deal with that.
    - Slight fixes to font and framebuffer drawing
    - Rudimentary word wrapping support for font rendering code
2022-04-12 Basic beeper melody driver
    - Wrote a basic driver that works with the beeper to play some basic
    melodies, which are just frequency/duty cycle/duration tuples, driven
    automatically by a timer.
    - Shut up some extra logging in timer/counter driver
    - Play an error sound when menu is pressed, but no menu action is
    available
2022-04-12 Add poll timer to HMI driver
    - Periodically poll the front panel IO expander if we haven't received
    an interrupt in a while.
    This guards against a case where we get quick back-to-back interrupts
    (perhaps because of a bouncy switch) which causes us to lose one of
    them, and then we won't get any more interrupts from the IO expander
    until we manually read it to clear the interrupt flags internal to it;
    this is kind of a hack but lol
    We may not need this with the rev2 front panel board (which features
    debouncing circuitry) but there's no harm in keeping it, though when
    we implement standby mode we'll need to stop this timer.
    [I2C.cpp]
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2022-04-14 USB driver fixes
    - Ensure the required AHB/APB clocks are enabled for the USB
    - Fixed the format of USB string descriptors (invalid order for the
    first word) and implemented reading out the serial correctly
    - Disable some I2C logging
    [I2C.cpp]
2022-04-15 Start work on USB vendor interface
    - Begin implementing the vendor endpoint handler. It will receive
    packets from the host with a particular (fixed) header that indicates
    the remaining length as well as the type of packet.
    It runs in its own task, separate from the primary USB stack task. It
    does get notified from that task when the USB connectivity state
    changes.
    - Added a "hidden" flag to GUI components
    - Remove some superfluous logging from external interrupt controller and
    gate it behind a flag
2022-04-15 GUI/font tweaks; start on main screen
    - Create a mockup of the main screen of the instrument. Currently it
    just shows the voltage/current, temperature, and has a section on the
    very left for a few 16x16 icons to indicate the current state.
    The current mode and load on/off indication will be done with
    indicators (or illuminated buttons) on the front panel.
    - Add a "divider" component, which just draws a vertical or horizontal
    line on the screen
    - Added some extra characters (degree symbol, 'C') to the number L/XL
    fonts so we can display temperatures
    - Fixed a screen clear bug in screen manager drawing
    - Add lights test to pinball task: when the task is started, we blink
    all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
    [Main.cpp]
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2022-04-17 Add icon support
    - Created icon class, which is a thin wrapper around bitmaps. Icons can
    be displayed arbitrarily on the screen.
    We've added two icons for use on the main screen.
    - Added a static icon component, which draws a single icon in the UI at
    the specified position
    - Updated main screen to show icons for external voltage sense and an
    active USB connection. These appear on the left edge of the screen
    before the current voltage/current settings.
    - Fixed overdrawing in rectangle primitive routine
    [Main.cpp]
2022-04-17 Add list view; main menu; selection event routing
    - Began work on the main screen menu, which appears when the menu button
    is pushed. This currently just allows controlling the sense input
    (switching between external and internal input) but will offer a few
    other options later also.
    - Created the list view, which renders fixed height rows and allows the
    user to scroll through them and issue selections
    - Basic event routing infrastructure in input manager, with the basis
    for handling selection between components. This is very basic and
    currently only the list view is hooked up to it.
    - Add support for blitting, as well as rendering fonts in inverted
    - Fixed an issue in load dr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
    [Main.cpp]
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2022-04-20 Minor tweaks for rev 2 front panel
    - Changed the IO line for the encoder center switch around on the front
    panel inputs
    - Add driver for on-board TRNG. This is a super basic synchronous mode
    operation which blocks the calling task in an infinite loop until a
    new word is available to read.
    This should be used to seed a software PRNG for more performance
    critical situations.
    - Illuminate status (error) LED when system panics
    [Main.cpp, Random.cpp]
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2022-04-22 Handle current reading
    - Read the input current from the ADC on the load board (only channel 1
    so far) and some rudimentary gain adjustment
    - Minor tweak to main screen display
    - Fixed encoder (for some reason, the "A" line does not work with the
    filter on, but "B" does. Disabling filter for "B" also breaks the
    whole fucking thing)
    [Main.cpp]
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2022-04-23 Implement numeric spinner control; basic current control
    - Added a numeric spinner input control, which handles encoder events to
    increment or decrement an integer value
    - Basic current control: a numeric spinner was added to the main screen
    - Fixed some off-by-one errors in drawing for scrollbars, and scrolling
    for list boxes
    - GUI component drawing flags (for selection, etc.)
    [Main.cpp]
2022-04-23 Add some missing part numbers to analog board
    - Some components on analog load were missing part numbers, so this adds
    them. It also fixes a few components with the same value, where some
    had a part number and others didn't.
    [acdc.kicad_sch, driver.kicad_pcb, driver.kicad_sch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]
2022-06-04 Re-design around STM32MP1 (#2)
    * Start work on rev3 hardware
    - This fits the Technomet R110 enclosure and supports multiple load
    boards, connected via CAN rather than I2C. Each load has a
    microcontroller of its own.
    * More new layout stuff
    - More work on the new controller board layout
    - Rework rear IO board for the new Technomet rear panel (it has an
    expansion connector for CAN also, and features four screw holes
    instead of two)
    - Added a few footprints (expansion RJ45 connector; some
    horizontal/vertical headers)
    * Work on controller VSense, power
    - Routed 3V3 switching supply
    - Created footprint and symbols for Kemet EA2 series latching relay
    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
    [VSense.kicad_sch, adc-dac.kicad_sch, analog-io.kicad_sch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]
2022-07-14 Rev4 front panel (#3)
    * hw: start work on new front panel board
    - This replaces all the various I2C chips with a single RP2040 (with
    some boot flash) to handle scanning the keyboard, driving PWM LEDs
    (including the display backlight) and actually handling the display
    controller initialization.
    - Flipped the pinout of the connector to the main controller board
    * hw: more front panel stuff
    - fixed the mirrored pinout for the connector to the controller board
    - Replaced a few capacitors to reduce BOM count
    - Start connecting signals to RP2040, including the flash connection
    (dedicated to it)
    * hw: First pass at new front panel
    - Finished routing all signals o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
    [buttons.kicad_sch, controller.kicad_sch, display.kicad_sch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]
2022-08-24 Initial port to STM32MP15x (#4)
    * fw: start porting to stm32mp15x
    - remove most of the old atmel-specific stuff; we won't need it on this
    new target
    - remove tinyusb (USB stack is handled by host side now) and littlefs
    (there is no NOR flash accessible to the firmware; storage is provided
    by software on the host side)
    - update readme
    * fw: add st sources
    - Add the ST drivers (LL and HAL) and integrate them into the vendor-st
    module in the firmware
    * fw: add malloc support
    - integrated umm_malloc into libc to provide the standard malloc() and
    friends. these work by defining a heap in memory, as outlined by the
    _sheap and _eheap symbols exported from the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
    [Gpio.cpp, Gpio.h, Mailbox.cpp]
